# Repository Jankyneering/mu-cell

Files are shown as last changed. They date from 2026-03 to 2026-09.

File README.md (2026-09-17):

<h1 align="center">µCell</h1>

<p align="center">
	µCell logo
</p>

<p align="center">An open-source SDR base station platform for digital and analog voice modes.</p>

Got a board? Start with the [Quick Start Guide](docs/quickStartGuide.md).

---

## Contents

- [What is µCell?](#what-is-µcell)
- [Where to Buy](#where-to-buy)
- [Build Your Own](#build-your-own)
- [How the Software Fits Together](#how-the-software-fits-together)
- [Documentation](#documentation)
- [How to Contribute](#how-to-contribute)
- [Acknowledgements & License](#acknowledgements--license)

---

## What is µCell?

µCell is a software-defined radio base station/repeater/transceiver that runs on a Raspberry Pi.

The µCell BB board puts an SX1255 transceiver, its RF front-end, and a HAT identification EEPROM on a board that sits on a Pi 3, 4, 5, or Zero 2W. A single command installs the driver, and from there you pick the radio software you want to run.

The board presents itself as a standard SoapySDR device. The project started with TETRA, but DMR, D-Star, YSF, P25, and analog FM run on the same board through MMDVM-IQ, and general-purpose SDR software works with it directly. The goal is to support every voice mode we can reach.

Everything is open. Schematics, PCB layouts, production outputs, 3D printed case designs, drivers, and the EEPROM tooling are all in this repository, under licences that let you build, modify, and sell your own.

<p align="center">
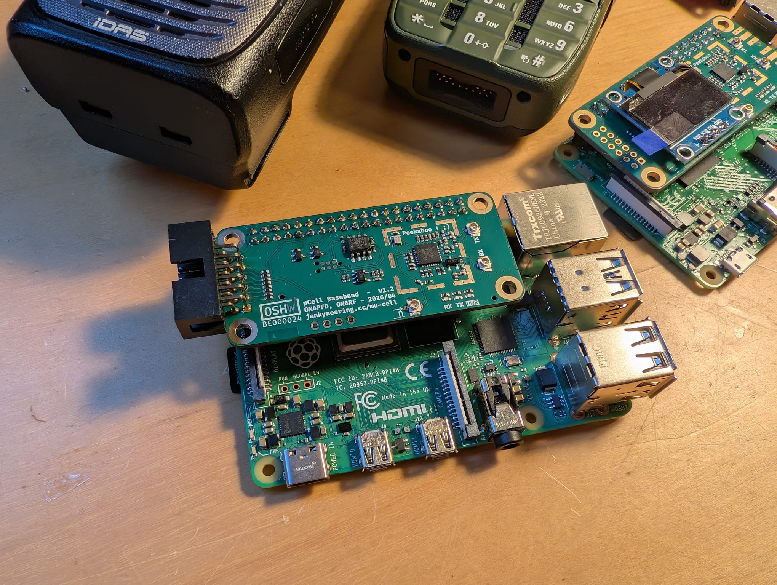
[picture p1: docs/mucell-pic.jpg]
µCell BB board
  
</p>

---

## Where to Buy

Assembled and tested µCell BB boards are sold by Fred Corp., one half of the Jankyneering team:

[store.fredcorp.cc](http://store.fredcorp.cc/)

Each board sold there is individually measured on an RF test set before shipping, and carries a signed EEPROM so the driver can confirm where it came from. See the [FAQ](docs/faq.md) for what signing does and does not mean.

---

## Build Your Own

The design is open and the production outputs are in this repository, ready to upload to a PCBA house. Component choice is critical: the RF path depends on inductor Q, capacitor dielectric, and a low drift referenceL. Foregoing proper part selection will affect sensitivity and output power.

See [docs/muCellBBManufacture.md](docs/muCellBBManufacture.md) for the production package contents, the stackup, the component selection notes, and the EEPROM writing procedure.

---

## Software structure

The stack has three layers.

### 1. µCell BB drivers

[mu-cell-bb-drivers](https://github.com/Jankyneering/mu-cell-bb-drivers) contains the device tree overlay that makes the Pi recognise the board, and `SoapyMuCell`, the hardware driver itself. The install script in this repository builds and installs both.

### 2. SoapySDR

`SoapyMuCell` registers with SoapySDR as the device `driver=mucell`. Any SoapySDR-aware application can open the board without knowing anything about the SX1255. This is the integration point: adding support for new software is usually a matter of pointing it at the right device string.

### 3. Applications

| Software | Modes | Status |
|---|---|---|
| [Flowstation](https://github.com/razvanzeces/flowstation) | TETRA, wider feature set, less stable | Supported |
| [Tetra-Bluestation](https://github.com/MidnightBlueLabs/tetra-bluestation) | TETRA, stable, fewer features | Supported on the testing branch, landing in main |
| [Nexus-BS](https://github.com/invictus737/nexus-bs/) | TETRA, different development direction than Flowstation | Untested, but claims support |
| [MMDVM-IQ](https://github.com/g4klx/MMDVM-IQ) | FM, DMR, D-Star, YSF, P25, POCSAG | Supported |

<!-- TODO: confirm the Bluestation branch wording, and whether MMDVM-IQ is "in progress" or already usable -->

Each of these is its own project with its own installation instructions. 
General-purpose SDR software reaches the board the same way, through the `driver=mucell` device string:

| Software | Status |
|---|---|
| [GQRX](https://www.gqrx.dk/) | Supported |
| [CubicSDR](https://cubicsdr.com/) | Supported |
| [GNU Radio](https://www.gnuradio.org/) | Should work through the Soapy blocks, more testing needed |
| [SDR++](https://www.sdrpp.org/) | Needs a dedicated source module, not yet written |

The [quick start guide](docs/quickStartGuide.md) covers how to point each one at the board.

---

## Documentation

| Document | Covers |
|---|---|
| [Quick Start Guide](docs/quickStartGuide.md) | Flash a Pi, install the driver, set up your radio software, get on air |
| [Building the Drivers](docs/buildDriver.md) | The driver and overlay built by hand, step by step, no scripts |
| [Hardware](docs/hardware.md) | Board specifications, connectors, measured performance, cases, roadmap |
| [Manufacturing](docs/muCellBBManufacture.md) | Production outputs, component selection, EEPROM writing and signing |
| [FAQ](docs/faq.md) | Common questions, support routes, the "not genuine" warning |

---

## How to Contribute

Contributions are welcome. For small fixes or documentation updates, feel free to open a pull request directly. For larger changes, open an issue first so the approach can be discussed. Keep pull requests focused and include a clear description of what changed and why.

Hardware contributions follow the same route. If you are proposing a layout or component change, include the reasoning and, where relevant, the measurements that back it up.

Support for a new mode or a new piece of SDR software is always of interest. If you get something working against `driver=mucell`, a short section for the quick start guide is a welcome contribution on its own.

---

## Acknowledgements & License

µCell builds on the work of several open-source projects:

- Tatu Peltola ([tejeez](https://github.com/tejeez/)), designer of the [SXCeiver](https://github.com/tejeez/sxxcvr), which provided early inspiration for compact SX1255-based SDR hardware.
- Wouter Bokslag ([Midnight Blue](https://github.com/MidnightBlueLabs/)) and contributors, authors of [TETRA-bluestation](https://github.com/MidnightBlueLabs/tetra-bluestation), which implements an open TETRA base station stack.

We also acknowledge the broader SDR and SoapySDR communities whose work enables hardware experimentation with modern radio systems.

Certified open source hardware by OSHWA under registration BE000024

OSHW BE000024 (https://certification.oshwa.org/be000024.html)

<!-- TODO: download the certification mark with the UID from the project page at certification.oshwa.org/be000024.html and commit it to docs/logos/. The link above assumes oshw-be000024.svg. -->

Hardware and documentation published under CreativeCommons BY-SA 4.0


[Creative Commons Attribution-ShareAlike 4.0 International License](http://creativecommons.org/licenses/by-sa/4.0/)

Software published under GNU GPLv3

License: GPL v3 (https://www.gnu.org/licenses/gpl-3.0.en.html)
[GNU GPLv3](https://www.gnu.org/licenses/gpl-3.0.en.html)

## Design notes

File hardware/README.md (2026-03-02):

# Hardware

Folder containing hardware design files, schematics, and documentation for the hardware side of the project.

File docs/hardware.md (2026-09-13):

# Hardware

The `hardware` directory contains the open hardware designs for the µCell ecosystem. Each board is a modular building block, so a system can be anything from a minimal hotspot to a more complete base station.

The platform is SDR-based and built around the SX1255 transceiver. The µCell driver exposes the board through SoapySDR, which is what lets it serve TETRA, DMR, D-Star, YSF, P25, analog FM, and whatever else gets added later without hardware changes.

Design files include schematics, PCB layouts, production outputs, case models, and the documentation needed for assembly and integration.

## Contents

- [Design goals](#design-goals)
- [µCell BB (Baseband)](#µcell-bb-baseband)
  - [Connectors and headers](#connectors-and-headers)
- [µCell Display](#µcell-display)
- [µCell PA Mini](#µcell-pa-mini)
- [Adding an amplifier](#adding-an-amplifier)
- [Cases](#cases)

---

## Design goals

- Modular architecture that scales from small hotspot deployments to higher power base stations
- SDR-based design that is not tied to any single radio mode
- Compatibility with Bluestation, Flowstation, MMDVM-IQ, and general SoapySDR software
- Readily available components wherever the RF performance allows it
- Reproducible designs suitable for small-scale manufacturing

---

## µCell BB (Baseband)

This is the board the project is built around, and the only one currently in production. It works on its own as a compact hotspot, and acts as the baseband and RF front-end when a PA board is added later.

<p align="center">
  µCell BB board
</p>

Features:

- SX1255 transceiver with RF filtering and matching network
- 38.4 MHz TCXO reference, 0.5 ppm, with an external clock option
- EEPROM for HAT identification, optionally signed
- U.FL connectors for TX, RX, and external clock
- Header for a standard SSD1306 OLED
- 12-pin IDC expansion connector
- Raspberry Pi HAT form factor, compatible with the Pi 3, 4, 5, and Zero 2W

Measured specifications (v1.0):

| Parameter | Value |
|---|---|
| Frequency coverage | 400 to 510 MHz |
| Rated output guaranteed | 430 to 440 MHz |
| Sample rates | 25, 50, 75, 150, 300, 600 kHz |
| Maximum signal bandwidth | 500 kHz |
| Tx power (Pi/4 DQPSK) | 0 to 3 dBm |
| Rx sensitivity (TETRA T1) | -117 dBm |

Coverage is set by the SX1255, which is specified for 400 to 510 MHz. The matching network is tuned for the 70 cm band, rated transmit power is guaranteed over 430 to 440 MHz. The board will tune and receive across the wider range, with output falling off towards the edges.

Sample rates are the reference clock divided down, following from the 38.4 MHz TCXO. The SX1255 digitises I and Q with 1-bit delta-sigma converters and decimates to the requested rate.

The SX1255 is designed for mobile devices, and its selectivity reflects that. On the bench, an interfering signal at -40 dBm and 10 MHz offset from the receive frequency is enough to start degrading the rated sensitivity. That is fine for a board transmitting a few dBm into its own antenna. It stops being fine as soon as you put an amplifier behind it. See [adding an amplifier](#adding-an-amplifier).

<!-- TODO: add supply current, and a measured figure for a non-TETRA mode, given the project is not TETRA-only. -->

Identification values written to the EEPROM:

| Field | Value |
|---|---|
| Vendor | Jankyneering |
| Product | µCell-BB |
| Product ID | `0x1255` |
| Current supply | 5000 mA |
| Device tree blob | `mu-cell-bb_raspberrypi` |

Boards sold by Jankyneering are individually tested on a radio test set to validate RF performance before shipping. See [muCellBBManufacture.md](muCellBBManufacture.md) if you want to build your own.

### Connectors and headers

#### External clock

A third U.FL connector accepts an external reference in place of the onboard TCXO. Useful if you have a GPSDO or a house standard, or if your application needs better than 0.5 ppm.

Boards ship using the onboard TCXO. To switch to the external input, cut JP1 on the back of the board and bridge the jumper to the external clock side.

Match the part you are replacing. The onboard reference is a Seiko Epson TG2016SMN 38.4000M-MCGNNM3: 38.4 MHz, sine output, ±0.5 ppm, running from the board's 3.3 V rail. An external source should be at 38.4 MHz with a comparable output level, and there is little point switching unless it is better than 0.5 ppm. The TCXO datasheet gives the exact output amplitude to aim for.

> Make sure your external source is present and at the right level before you cut, or the board will have no reference at all.

<!-- TODO: add a photo of JP1 on the back of the board -->

#### OLED display header

A 4-pin header for a standard 0.96 inch SSD1306 OLED, wired to the Pi's I2C bus.

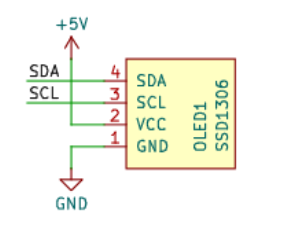
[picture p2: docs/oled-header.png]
SSD1306 OLED header schematic


| Pin | Signal |
|---|---|
| 1 | GND |
| 2 | VCC (+5V) |
| 3 | SCL |
| 4 | SDA |

There is no µCell software support for the display yet. It sits on the standard Pi I2C bus, so any existing SSD1306 library works in the meantime.

#### Expansion connector (J5)

A 2x6 12-position IDC connector on 2.54 mm pitch, for accessories and future modules, including the µCell Display. It breaks out power, the TX and RX lines, I2C, and two spare GPIOs. Every signal line goes through a 100R series resistor.

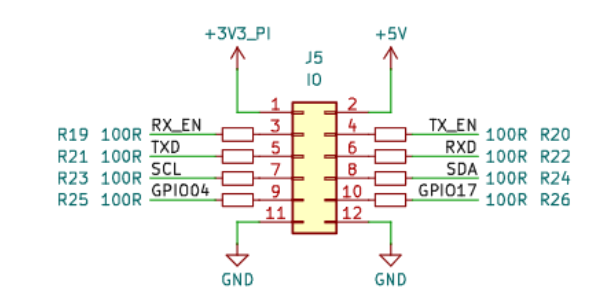
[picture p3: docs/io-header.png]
J5 expansion connector schematic


| Pin | Signal |
|---|---|
| 1 | +3V3 (from Pi) |
| 2 | +5V |
| 3 | RX_EN |
| 4 | TX_EN |
| 5 | TXD |
| 6 | RXD |
| 7 | SCL |
| 8 | SDA |
| 9 | GPIO04 |
| 10 | GPIO17 |
| 11 | GND |
| 12 | GND |

---

## µCell Display

A front panel module for builds that go into an enclosure, connecting through J5. The design is nearing completion.

Features:

- 0.96 inch SSD1306 OLED for status
- Rotary encoder for local control
- Status LEDs

<!-- TODO: add panel dimensions and a photo once the design is finalised -->

---

## µCell PA Mini

A low power RF front-end that extends the µCell BB. The design exists but there is still a fair amount of work left before it is ready to manufacture.

Planned features:

- Roughly 1 W RF power amplifier
- Receive path conditioning with an LNA
- Preselector filtering
- RF measurement and monitoring points

---

## Adding an amplifier

The µCell BB is a bare transceiver board. The matching network and filtering on it were designed to get the most output power and sensitivity out of the SX1255, and a board on its own has harmonics well within spec. Anything you put after it is your responsibility, and the SX1255 was designed for handheld and mobile equipment rather than for driving a power amplifier.

Two things matter once you amplify: linearity and filtering.

### Linearity

Modes with a non-constant envelope, TETRA among them, need a linear amplification chain. Constant-envelope modes such as FM and 4FSK are far more forgiving, so how much of this applies depends on what you are running.

The problem is rarely harmonic distortion. It is inter-channel interference, seen as increased adjacent channel power. As an amplifier is driven towards its P1dB point, the output level at which gain compression sets in, non-linear effects grow quickly. The carrier can still look clean while energy spreads into the channels either side of it.

A TETRA amplification stages usually follow these guidelines:

- Running far below P1dB, by oversizing the amplifier deliberately. A 10 W rated device producing 1 W of RF is a normal ratio.
- Using Class A or Class AB operation, which is one reason TETRA transmitter efficiency rarely exceeds about 20%.
- Adding a linearisation loop, often a Cartesian loop, which measures the distortion and pre-corrects the signal so the non-linear effects cancel out.

Those measures go together with tight filtering and closed loop power control. For lab, experimental, and amateur work, staying well below P1dB already gives acceptable results on its own.

The Bluestation documentation covers this in more depth and has worked examples: [Miscellaneous](https://github.com/MidnightBlueLabs/tetra-bluestation-docs/wiki/20-Miscellaneous).

### Filtering

Transmit filtering is the amplifier chain's job. 

Receive rejection matters just as much. The measured figure gives a sense of the margin available: a -40 dBm interferer 10 MHz away from the receive frequency already starts degrading rated sensitivity. Your own transmitter, amplified, is far stronger than that and far closer in frequency. Without proper rejection between the two paths, a duplexer or cavity filtering depending on what you are building, the receiver will be deaf whenever the transmitter is keyed.

None of this is exotic for anyone who has built a repeater before. It is worth saying plainly because the board is small and cheap enough to make a 100 W base station look like a matter of bolting on an amplifier, and it is not.

---

## Cases

3D printable case designs are in the `hardware` directory alongside the board files, under the same CC BY-SA 4.0 licence. They are designed to print without supports on a standard FDM machine.

<!-- TODO: give the exact path to the case models, the file formats provided (STL, STEP, source), and which Pi models each case fits -->

If you print one and find something that needs adjusting, a pull request with the change and a note on your print settings is welcome.

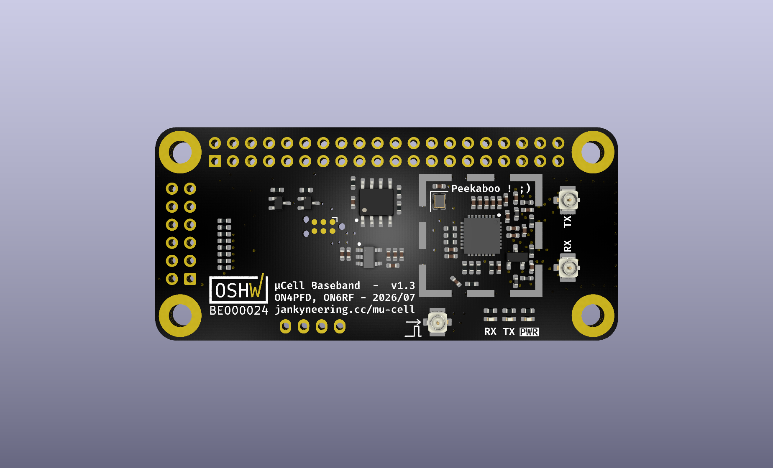
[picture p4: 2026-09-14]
hardware/mu-cell-bb/images/mu-cell-bb-top.png

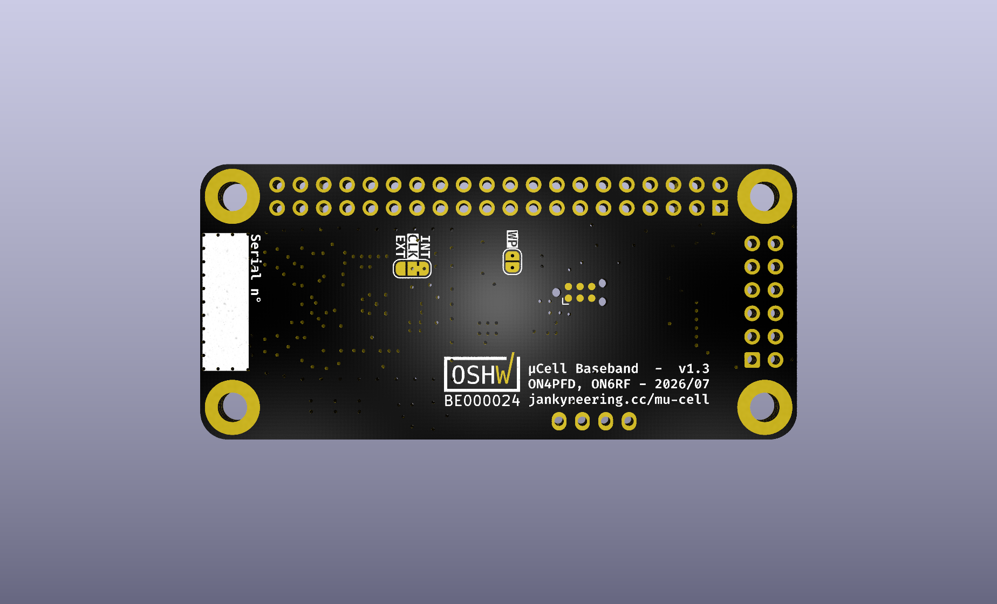
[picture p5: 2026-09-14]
hardware/mu-cell-bb/images/mu-cell-bb-bottom.png

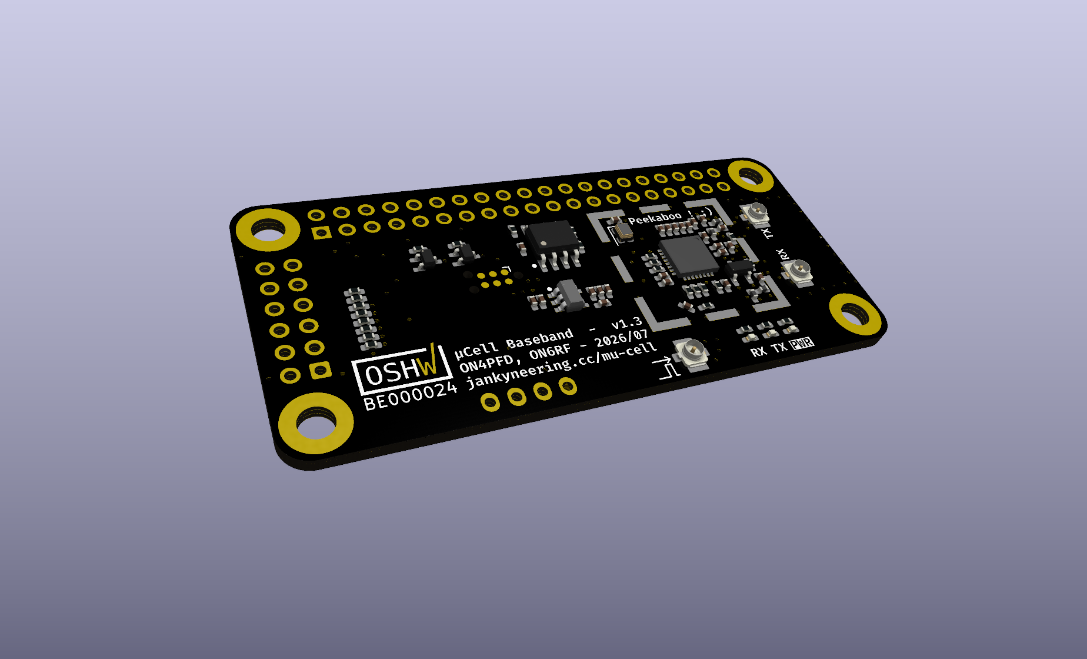
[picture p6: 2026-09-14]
hardware/mu-cell-bb/images/mu-cell-bb-3-4.png

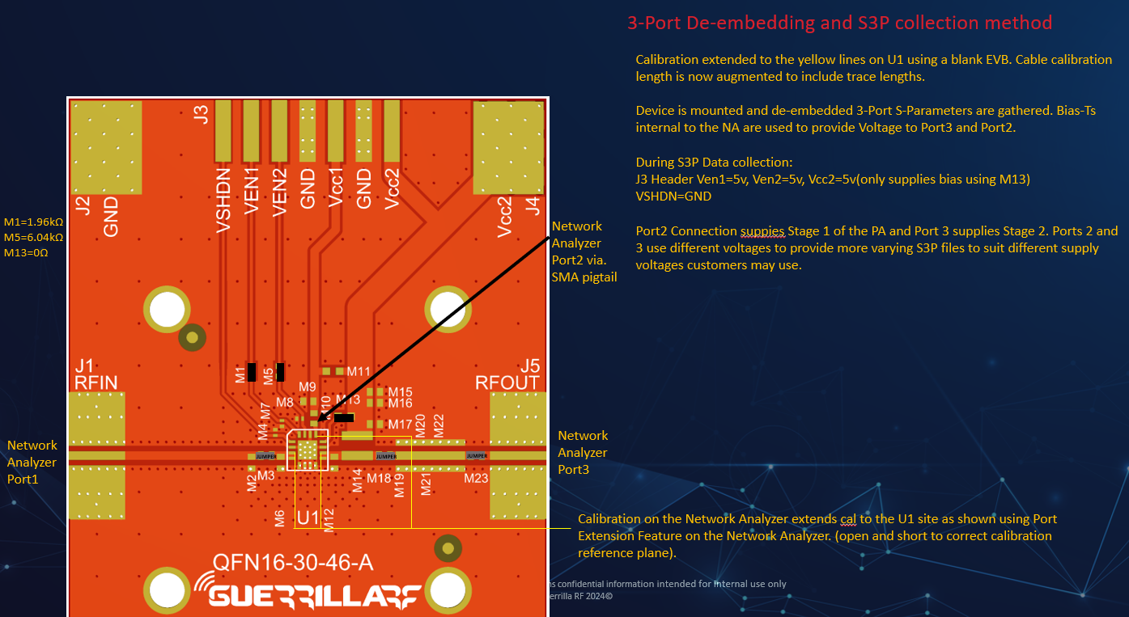
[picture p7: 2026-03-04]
sim/qucs/GRF5604_S3P/GRF5604_3Port_Deembed_Process.png

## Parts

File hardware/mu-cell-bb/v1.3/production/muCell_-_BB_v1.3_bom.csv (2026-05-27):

Designator | Footprint | Quantity | Value | LCSC Part #
_2, | e7774905-3e1b-474f-b2b7-99bac235eba3 | 2
C1, C2, C6, C8 | 0402 | 4 | 100p | C2941926
C10, C11, C12, C14, C16, C21, C24, C7, C9 | 0402 | 9 | 100n | C60474
C13, C15, C17, C18, C19, C22 | 0402 | 6 | 10n | C60133
C20, C23 | 0402 | 2 | 1u | C29266
C25 | 0402 | 1 | 4.7u | C23733
C3 | 0402 | 1 | 3.3p | C2941931
C4 | 0402 | 1 | 8.2p | C2857971
C5 | 0402 | 1 | 6.8p | C1864373
D1 | SOT-23-3 | 1 | BAV99,215 | C2500
IC1 | QFN50P500X500X80-33N-D | 1 | SX1255IWLTRT | C89372
J1 | U.FL_Vertical_Passthrough | 1 | TX | C5137195
J2 | U.FL_Vertical_Passthrough | 1 | RX | C5137195
J3 | U.FL_Vertical_GND | 1 | EXT_CLK | C5137195
L1, L3, L4 | 0402 | 3 | 39n | C40399699
L2 | 0402 | 1 | 22n | C22440906
LED1 | 0402 | 1 | Red | C7496803
LED2 | 0402 | 1 | Amber | C5123495
LED3 | 0402 | 1 | Green | C74338
Q1, Q2 | SOT-323_SC-70 | 2 | BC817-40W | C383187
R1, R19, R2, R20, R21, R22, R23, R24, R25, R26, R3, R4, R5, R6, R7 | 0402 | 15 | 100R | C106232
R10, R8, R9 | 0402 | 3 | 1M | C26083
R11, R12, R13 | 0402 | 3 | 3K9 | C2909346
R14, R15, R16, R17, R18 | 0402 | 5 | 1K | C106235
U1 | SOIC-8_3.9x4.9mm_P1.27mm | 1 | 24LC256 | C615210
U2 | SOT23-5L_1P75X3P05X0P95_STM | 1 | LDK130M33R | C2969807
Y1 | Crystal_SMD_2016-4Pin_2.0x1.6mm | 1 | 38.4MHz | C1987359

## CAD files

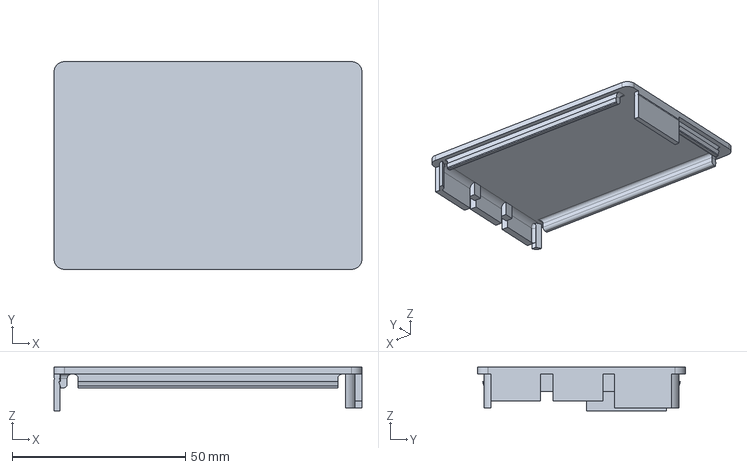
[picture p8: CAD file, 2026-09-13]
hardware/3d-print/Case.FCStd
89.0 x 60.0 x 12.6 mm

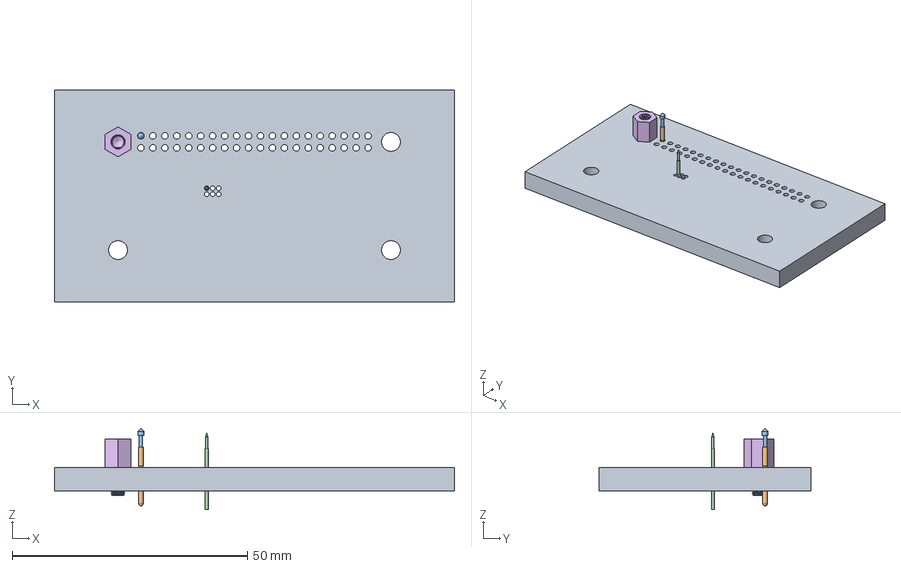
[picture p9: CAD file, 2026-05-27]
hardware/mu-cell-bb/CAD/mu-cell-bb_testbench-fixture.FCStd
85.0 x 45.0 x 17.3 mm
pin
P50-E1
root

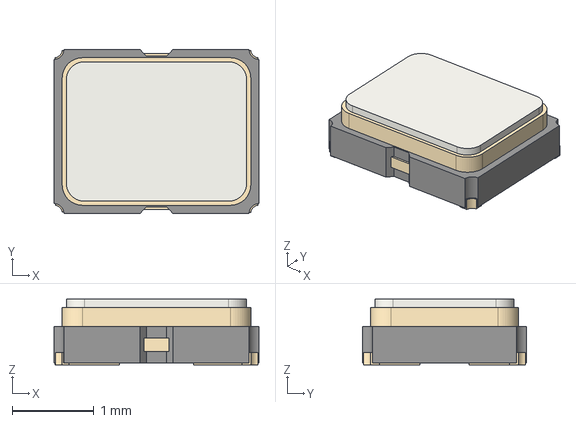
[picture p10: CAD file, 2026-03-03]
hardware/mu-cell-bb/parts/3D/Oscillator_SMD_SeikoEpson_SG210-4Pin_2.5x2.0mm.step
2.50 x 2.00 x 0.8 mm

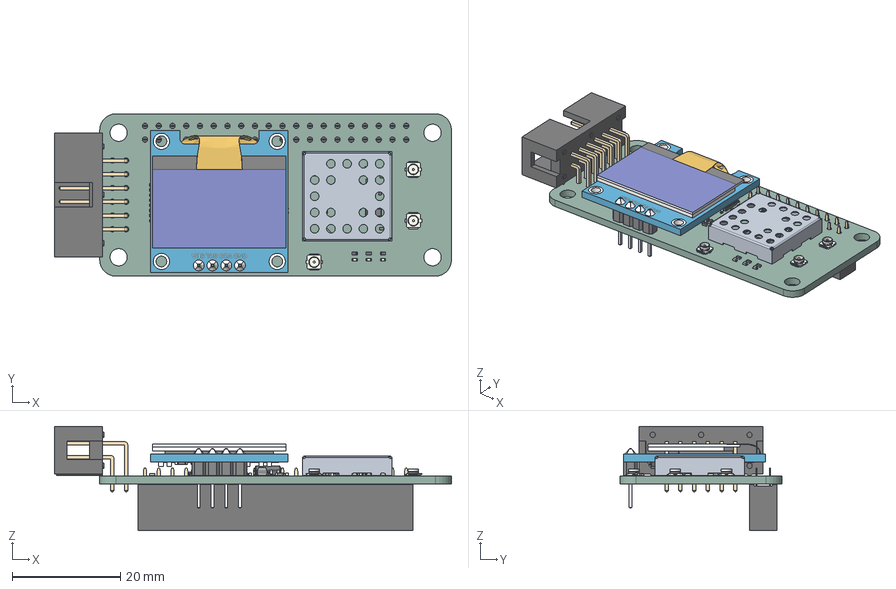
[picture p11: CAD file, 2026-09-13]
hardware/3d-print/muCell.step
73.3 x 30.0 x 19.3 mm
R_0402_1005Metric x 26
U.FL_Hirose_U.FL-R-SMT-1_Vertical x 2
SOT-323_SC-70 x 2
C_0402_1005Metric x 25
L_0402_1005Metric x 4
SOT23-5L_1P75X3P05X0P95_STM
2118707-4-CAN
Crystal_SMD_2016-4Pin_2.0x1.6mm
IDC-Header_2x06_P2.54mm_Horizontal
SOIC-8_3.9x4.9mm_P1.27mm
SOT-23-3
board
screen
pin_header
soldering
smd_capacitor
smd_capacitor (1)
914_smd_resistor
472_smd_resistor x 3
t4_smd_diode
smd_capacitor (2)
smd_capacitor (3)
smd_capacitor (4)
smd_capacitor (5)
smd_capacitor (6)
472_smd_resistor (1)
SOT-23_XC6206 v3
smd_capacitor (7)
flat_cable
LED_0402_1005Metric x 3
U.FL_Vertical
ThermalPin
PinsArrayLR
PinsArrayTB
PinSocket_2x20_P2.54mm_Vertical
mu-cell-bb_PCB

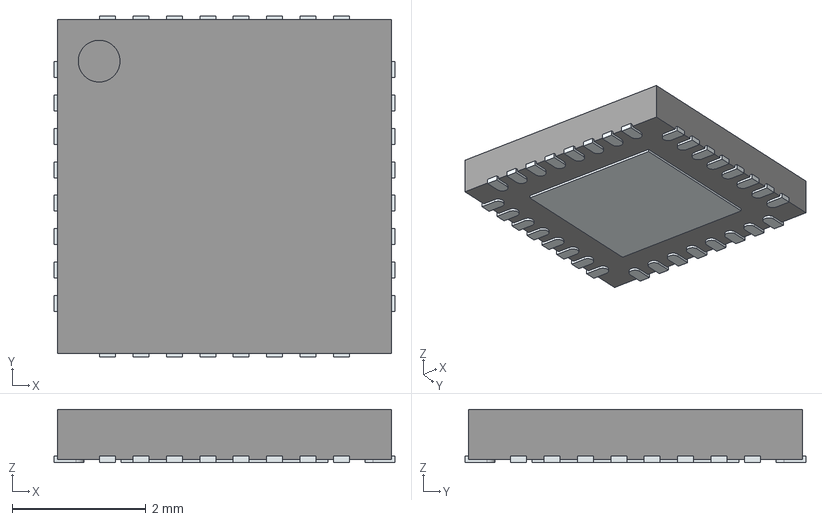
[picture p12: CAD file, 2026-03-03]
hardware/mu-cell-bb/parts/3D/SX1255IWLTRT.stp
5.10 x 5.10 x 0.8 mm
ThermalPin
PinsArrayLR
PinsArrayTB

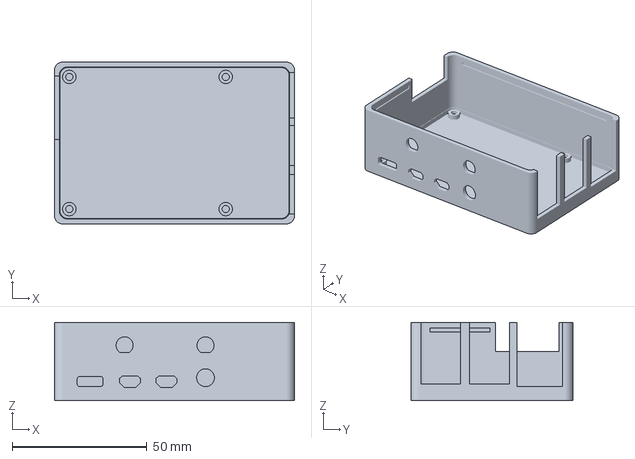
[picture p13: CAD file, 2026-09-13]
hardware/3d-print/Case_Bottom_Pi4.3mf
89.0 x 60.0 x 29.0 mm

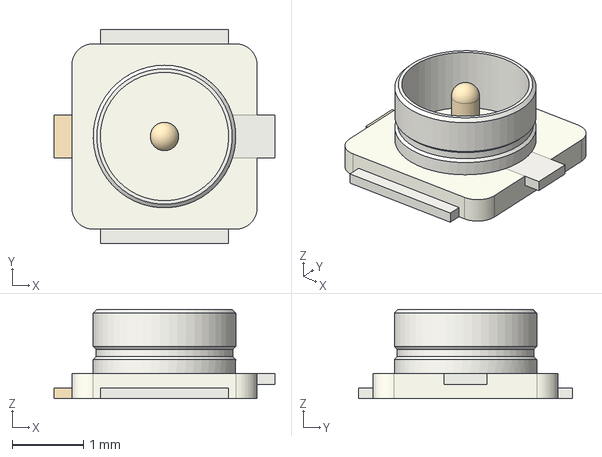
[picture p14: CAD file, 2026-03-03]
hardware/mu-cell-bb/parts/3D/U.FL_Vertical.step
3.10 x 3.00 x 1.25 mm

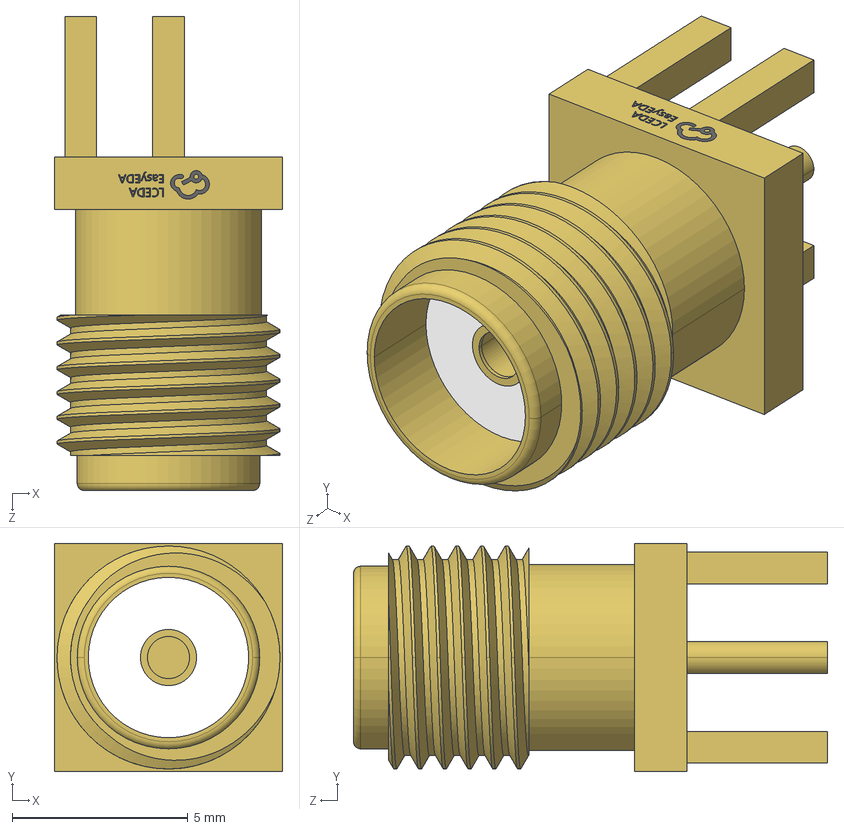
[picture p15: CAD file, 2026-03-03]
hardware/mu-cell-bb/parts/3D/SMA_Side.step
6.50 x 6.50 x 13.5 mm

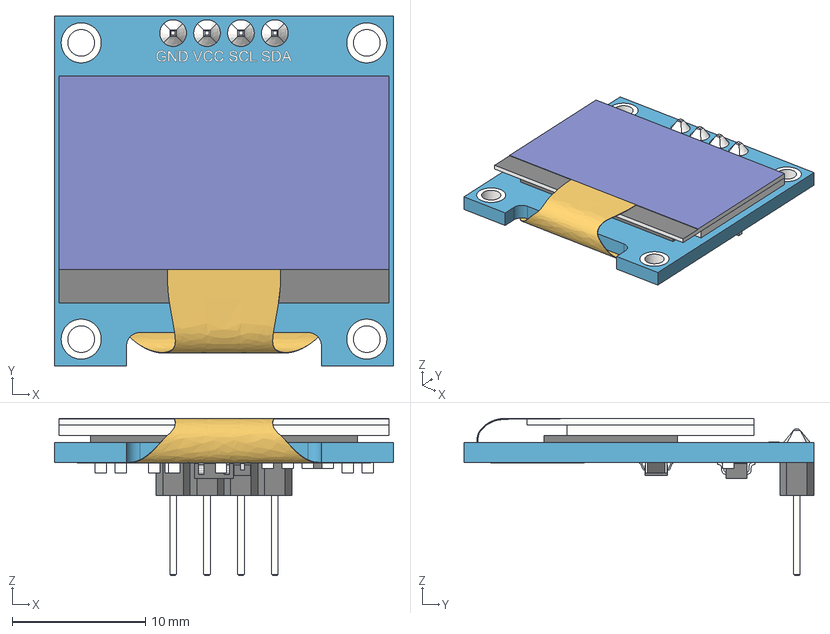
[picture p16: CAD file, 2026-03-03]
hardware/mu-cell-bb/parts/3D/OLED_128x64_I2C.step
25.4 x 26.2 x 11.8 mm
board
screen
pin_header
soldering
smd_capacitor
smd_capacitor (1)
914_smd_resistor
472_smd_resistor x 3
t4_smd_diode
smd_capacitor (2)
smd_capacitor (3)
smd_capacitor (4)
smd_capacitor (5)
smd_capacitor (6)
472_smd_resistor (1)
SOT-23_XC6206 v3
smd_capacitor (7)
flat_cable

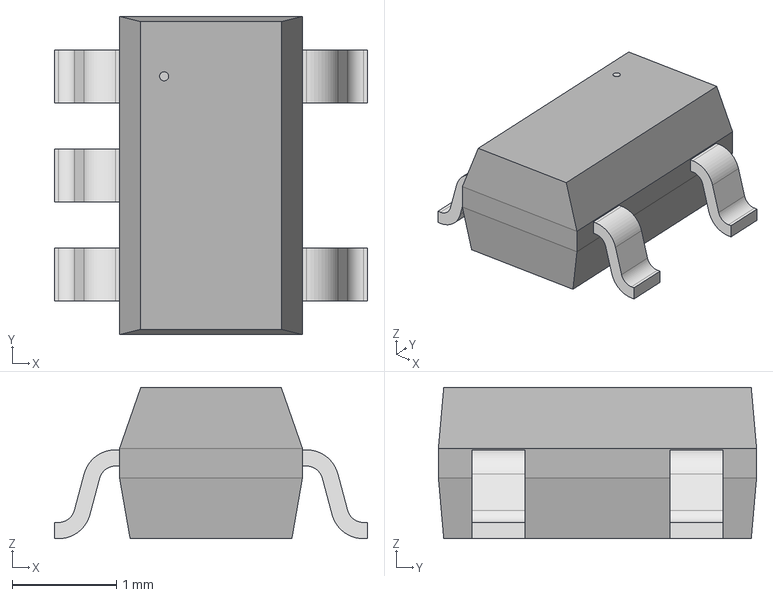
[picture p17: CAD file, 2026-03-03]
hardware/mu-cell-bb/parts/3D/SOT23-5L_1P75X3P05X0P95_STM.step
3.00 x 3.05 x 1.45 mm

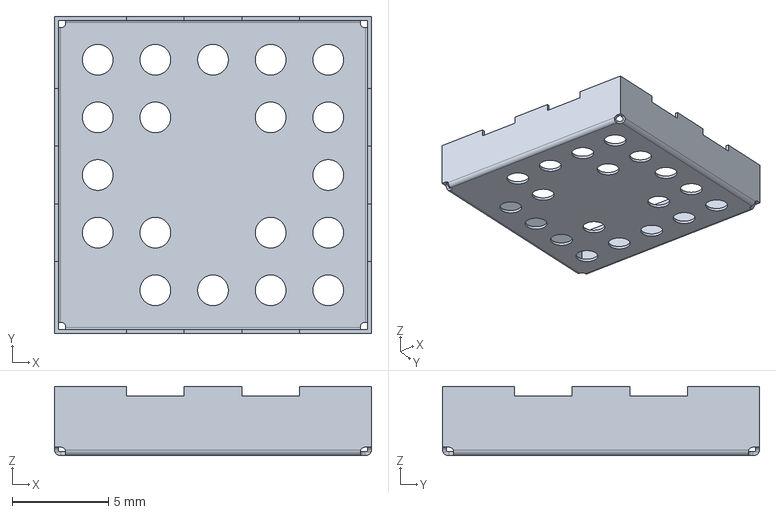
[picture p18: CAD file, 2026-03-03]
hardware/mu-cell-bb/parts/3D/2118707-4-CAN.STEP
16.5 x 16.5 x 3.60 mm

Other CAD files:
hardware/3d-print/Case-Case_Top_Pi4.3mf

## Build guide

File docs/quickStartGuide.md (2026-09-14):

# Quick Start Guide

This gets a µCell board running on a Raspberry Pi, from a blank SD card to working radio software.

If you would rather build the driver by hand instead of running an install script, see [buildDriver.md](buildDriver.md).

## Contents

- [What you need](#what-you-need)
- [Part 1: Install the board and driver](#part-1-install-the-board-and-driver)
  - [1. Flash and boot](#1-flash-and-boot)
  - [2. Run the install script](#2-run-the-install-script)
  - [3. Verify the driver](#3-verify-the-driver)
- [Part 2: Install and configure your radio software](#part-2-install-and-configure-your-radio-software)
  - [Flowstation](#flowstation)
  - [Tetra-Bluestation](#tetra-bluestation)
  - [MMDVM-IQ](#mmdvm-iq)
  - [Other SoapySDR software](#other-soapysdr-software)
- [Updating](#updating)
- [Troubleshooting](#troubleshooting)

---

## Equiment needed

- A Raspberry Pi 3, 4, 5, or Zero 2W
- A µCell BB board connected to the Pi
- A microSD card with Raspberry Pi OS Lite (64-bit)

Fit the board before you start. The device tree overlay only loads when the Pi detects the µCell on the GPIO header, so a Pi booted without the board will behave as though nothing is installed.

---

## Part 1: Install the board and driver

This part is the same regardless of which radio software you plan to run.

### 1. Flash and boot

Flash Raspberry Pi OS Lite (64-bit) to your microSD card using the [Raspberry Pi Imager](https://www.raspberrypi.com/software/). Enable SSH in the imager settings before writing, then boot the Pi and connect over SSH.

### 2. Run the install script

```bash
bash -c "$(curl -fsSL https://raw.githubusercontent.com/Jankyneering/mu-cell/main/install-mu-cell-sw.sh)"
```

The script will:

- Install the required system dependencies
- Clone the µCell baseband driver repository
- Build and install the device tree overlay
- Build and install the SoapyMuCell driver

> A reboot is required after the first install so the device tree overlay loads. The script will prompt you. Run it again after rebooting to verify the driver.

### 3. Verify the driver

After the reboot, the script probes the driver for you. To check it yourself at any point:

```bash
SoapySDRUtil --probe=driver=mucell
```

The driver reports the EEPROM contents during initialisation, including vendor, product, serial, and whether the signature matched a known key. A warning about an unsigned or unrecognised board does not stop it from working. See the [FAQ](faq.md) for what that means.

Once the probe succeeds, the board is ready and any SoapySDR application can use it.

---

## Part 2: Install and configure your radio software

Each of these is a separate project with its own releases and its own documentation. Pick the one you want, install it from upstream, then use the notes here for the µCell-specific parts.

### Flowstation

TETRA base station software with a wide feature set, at the cost of some stability. It publishes pre-built binaries that already work with µCell, which makes it the fastest route to a running cell.

On the Pi, fetch the binary and make it executable:

```bash
wget https://github.com/razvanzeces/flowstation/releases/download/v0.4.0/bluestation-bs
chmod +x bluestation-bs
```

Check the [releases page](https://github.com/razvanzeces/flowstation/releases) for a newer version than the one above.

Generate a `config.toml` for your cell with the configuration tool:

https://bluestation.russel053.com/

Either copy/paste the contents of the generated file via SSH (while editing config.toml for instance), or transfer the file via scp:

```bash
scp config.toml <user>@<pi-address>:~/
```

Then start the base station:

```bash
./bluestation-bs ./config.toml
```

### Tetra-Bluestation

Stable TETRA base station software with a smaller feature set.

µCell support currently lives on the testing branch and is expected to land in main. Get it from the [project repository](https://github.com/MidnightBlueLabs/tetra-bluestation), and build from source. Pi 5 and earlier Pi models use different builds, so pick the matching asset.

It uses the same binary name and the same configuration format as Flowstation, so the configuration tool above works for it too and the command to start it is identical:

```bash
./bluestation-bs ./config.toml
```

Keep them in separate directories if you want both on the same Pi.

### MMDVM-IQ

Multi-mode digital voice: FM, DMR, D-Star, YSF, P25, and others. Support is in progress.

Follow the build and configuration instructions in the [upstream repository](https://github.com/g4klx/MMDVM-IQ), and point it at the SoapySDR device `driver=mucell`.

### Other SoapySDR software

The µCell BB registers as a standard SoapySDR device, so anything that speaks SoapySDR can use it. With the board fitted and the driver from Part 1 installed, most sofware will list it in the available devices. 

| Software | Status |
|---|---|
| GQRX | Supported. The board appears in the device dropdown, select it and go. |
| CubicSDR | Tested working. Picked up at startup. |
| GNU Radio | Should work through the Soapy Source and Sink blocks. Lightly tested so far. |
| SDR++ | Needs a dedicated source module, which has not been written yet. |

If you ever do need to name the device by hand, for a GNU Radio block or a command line tool, the string is:

```
driver=mucell
```

<!-- TODO: this section is the extension point. When a new mode or stack is brought up, add a sibling heading here with a link upstream. -->
---

## Updating

Re-run the install script to update the driver and overlay:

```bash
bash -c "$(curl -fsSL https://raw.githubusercontent.com/Jankyneering/mu-cell/main/install-mu-cell-sw.sh)"
```

It checks the driver repository for new commits and rebuilds only if there are any. If nothing has changed, it says so and exits.

This is also how you pick up new EEPROM signing keys. If a board bought from the store started warning that it is not genuine, a driver update is usually the fix.

Radio software is updated through its own project, following whatever process that project uses.

---

## Troubleshooting

The driver probe fails right after install
: Reboot. The overlay is only read at boot. Re-run the install script afterwards.

The probe fails after a reboot
: Check that the board is seated properly on the GPIO header. The overlay will not load without it. Look for the HAT in the device tree with `ls /proc/device-tree/hat/`. If that directory is missing, the Pi is not seeing the EEPROM.

The driver warns that no public keys are compiled in
: The driver was built without any `.pem` files in `public_keys/`. It still works. Rebuild with the keys present if you want signature checking.

The radio starts but the frequency is off
: If you cut JP1 to use an external reference, check that the external source is present and at the right level. See [hardware.md](hardware.md#external-clock). If you want to use the internal source and need better accuary, compensate it in software (most implement a ppm correction line in the configuration files).

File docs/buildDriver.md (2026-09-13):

# Building the Drivers Manually

The [install script](quickStartGuide.md) does everything on this page for you. This is the same procedure done by hand, for anyone who would rather not pipe a script into bash, or who is porting the driver somewhere the script does not cover.

This page covers the device tree overlay and the SoapySDR driver, which is all µCell maintains. The radio software that sits on top is maintained by other projects, and their own documentation is the right place for build instructions. Once the driver is installed, any of them can reach the board through `driver=mucell`.

Every step below corresponds to a function in `install-mu-cell-sw.sh`, so you can read the script alongside this page.

## Contents

- [1. System dependencies](#1-system-dependencies)
- [2. Clone the driver repository](#2-clone-the-driver-repository)
- [3. Build and install the device tree overlay](#3-build-and-install-the-device-tree-overlay)
- [4. Build and install SoapyMuCell](#4-build-and-install-soapymucell)
- [5. Verify](#5-verify)
- [Next steps](#next-steps)

---

## 1. System dependencies

```bash
sudo apt update
sudo apt install -y --no-install-recommends \
  git make g++ cmake \
  libsoapysdr-dev soapysdr-tools libasound2-dev python3-soapysdr \
  libssl-dev clang llvm-dev libclang-dev
```

What these are for:

| Package group | Why |
|---|---|
| `git make g++ cmake` | Build toolchain |
| `libsoapysdr-dev soapysdr-tools python3-soapysdr` | SoapySDR headers, the `SoapySDRUtil` probe tool, and Python bindings |
| `libasound2-dev` | ALSA, used for the sample interface |
| `libssl-dev` | OpenSSL, required for EEPROM signature verification |
| `clang llvm-dev libclang-dev` | Needed by the build |

---

## 2. Clone the driver repository

```bash
git clone https://github.com/Jankyneering/mu-cell-bb-drivers ~/mu-cell-bb-drivers
```

The install script clones into `$HOME/mu-cell-bb-drivers`. The paths below assume the same.

To update an existing clone instead:

```bash
cd ~/mu-cell-bb-drivers
git fetch origin
git pull --ff-only
```

If the pull brings in changes, rebuild both the overlay and the driver before using the board again.

---

## 3. Build and install the device tree overlay

The overlay tells the Pi how to talk to the board. Without it, the driver has nothing to attach to.

Fit the µCell to the GPIO header before you go any further. The overlay is loaded from the HAT EEPROM at boot, so it will not load at all on a Pi with no board attached.

```bash
cd ~/mu-cell-bb-drivers/raspberry-pi-drivers/mu-cell-bb-dts
make overlay
sudo make install
```

`make overlay` compiles `mu-cell-bb_raspberrypi.dts` into a `.dtbo` in `build/`. `make install` copies it to the overlays directory, which is `/boot/firmware/overlays` on current Raspberry Pi OS and `/boot/overlays` on older releases. The Makefile detects which one you have.

Reboot now:

```bash
sudo reboot
```

The overlay is only read at boot, so nothing below will work until you have done this.

---

## 4. Build and install SoapyMuCell

```bash
cd ~/mu-cell-bb-drivers/SoapyMuCell
mkdir -p build
cd build
cmake ..
make
sudo make install
sudo ldconfig
```

During configuration, CMake scans `public_keys/` and embeds every `.pem` file it finds into `generated_keys.hpp`. Each key is named after its filename, so batch keys show up by name in the driver log. If the directory is empty, CMake prints a warning and the driver reports `NO_KEYS_COMPILED_IN` at runtime. That is not fatal, it just means signature checking is off.

---

## 5. Verify

```bash
SoapySDRUtil --probe=driver=mucell
```

On success the driver logs a line summarising the EEPROM, for example:

```
HAT EEPROM: Vendor="Jankyneering" Product="µCell-BB" UUID=... HW=1.0 Serial=... Auth=GENUINE (key: batch_001)
```

Possible `Auth` values and what they mean:

| Value | Meaning |
|---|---|
| `GENUINE` | Signature matched one of the compiled-in keys |
| `NO_SIGNATURE` | The EEPROM has no signature atom. Normal for boards you wrote yourself |
| `SIGNATURE_MISMATCH` | A signature is present but matches no known key. Often an out-of-date driver |
| `NO_KEYS_COMPILED_IN` | Built without any `.pem` files in `public_keys/` |
| `EEPROM_NOT_FOUND` | The Pi is not seeing the HAT EEPROM at all. Check the board is seated |

None of these block operation. The driver warns and carries on.

---

## Next steps

The driver is now installed and the board is a standard SoapySDR device. Install whichever radio software you want according to its own documentation, and point it at `driver=mucell`.

[quickStartGuide.md](quickStartGuide.md#part-2-configure-your-software) has a short configuration section for each stack we have tested, with links upstream.

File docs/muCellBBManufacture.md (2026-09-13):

# Manufacturing a µCell BB

Everything needed to have a µCell BB built is in this repository. This page covers ordering the boards, the component choices that actually matter, and writing the EEPROM afterwards.

Boards sold through [store.fredcorp.cc](http://store.fredcorp.cc/) are individually tested on a radio test set to validate RF performance before they ship. If you build your own, that verification step is on you, and the section on [testing](#testing-what-you-built) is worth reading before you order a large batch.

## Contents

- [The production package](#the-production-package)
- [Board settings](#board-settings)
- [Component selection](#component-selection)
- [Testing what you built](#testing-what-you-built)
- [Writing the EEPROM](#writing-the-eeprom)
- [Signing](#signing)
- [Support for boards you built yourself](#support-for-boards-you-built-yourself)

---

## The production package

Production outputs live under `/hardware/mu-cell-bb/<version>/production`. For the current revision that is:

```
/hardware/mu-cell-bb/v1.3/production
```

| File | Purpose |
|---|---|
| Gerber zip | Copper, mask, silkscreen, and drill data. Upload as-is |
| BOM CSV | Component list with LCSC part numbers |
| Designators CSV | Reference designator list for assembly |
| Positions CSV | Component positions and rotations |
| IPC netlist | Netlist for electrical test and for verifying the gerbers match the schematic |

Upload the gerber zip in the JLCPCB order form, then attach the BOM and positions files in the assembly step. The parts list uses LCSC numbers so the matching is automatic for most lines.

The IPC netlist is worth uploading too where the fab accepts it. It lets them catch a gerber that does not match the intended connectivity before anything is etched.

---

## Board settings

These are the settings used for the boards Jankyneering manufactures.

| Setting | Value |
|---|---|
| Layers | 4 |
| Thickness | 1.6 mm |
| Outer copper weight | 1 oz |
| Inner copper weight | 0.5 oz |
| Impedance control | None specified |
| Surface finish | ENIG recommended |

No controlled impedance was ordered. The RF traces were designed against the standard 4-layer 1.6 mm stackup, and the measured performance in [hardware.md](hardware.md) was achieved without it. Changing the layer count or the overall thickness changes the trace impedance, which shows up as lost output power and degraded sensitivity, so keep the stackup as listed rather than treating these numbers as defaults.

---

## Component selection

The BOM specifies parts rather than values for a reason. Assembly houses substitute freely when a line is out of stock, and for most of this board that is fine. For the RF path it is not.

The full list is in the BOM CSV in the production folder, with an LCSC number on every line. Look those numbers up rather than reading values off the schematic: the parts chosen carry tolerance, dielectric, and Q figures that a value alone does not capture. The categories below are the ones to check before approving any substitution.

### Reference clock

Y1 is a 38.4 MHz TCXO. Frequency accuracy and stability over temperature set the carrier accuracy of the whole radio, and several of the modes the board targets have demanding requirements there. The board is built with a 0.5 ppm part.

Any TCXO meeting the same specification works. What matters is the frequency, the stability figure, the output type and level the SX1255 expects, and the supply voltage. Do not substitute on frequency alone: a plain crystal, or a TCXO an order of magnitude looser, will pass a bench test and then drift out as the board warms up.

If you need better than the onboard part gives you, an external reference can be fed in through J3 instead. See [hardware.md](hardware.md#external-clock) for how to switch the board over.

### Inductors in the matching network and filters

Q factor is the parameter that matters, not just inductance. A part with the correct value but a lower Q will widen the filter response and eat transmit power.

L2 gives the standard to work to. It is a Coilcraft 0402CS-22NXGRW, 22 nH, with Q of 53 at 900 MHz and 53 at 1.7 GHz. That is a wirewound ceramic part, and a general-purpose multilayer 22 nH inductor is not a substitute for it even though a BOM matcher will treat them as the same line.

Check Q at your operating frequency rather than the datasheet headline figure, which is usually quoted much lower down, and make sure the self-resonant frequency sits well above the band of operation.

### Capacitors in the RF path

C3, C4, and C5 set the matching network, and C1, C2, C6, and C8 sit in the RF path. Use the parts the BOM lists.

C5 shows the level of part these lines need: a Murata GCM1555C1H6R8FA16D, 6.8 pF, C0G dielectric, 50 V, in 0402. C0G is the requirement, not a preference. X7R and X5R have voltage and temperature coefficients large enough to detune a matching network, and they are microphonic. A 6.8 pF X7R part is not a substitute even though a BOM line matcher will treat them as the same value.

Tolerance matters too, since loosening it spreads your performance across a batch.

### Everything else

Decoupling capacitors, pull-up resistors, LEDs, and the transistors tolerate substitution without much consequence. The EEPROM should be a 24LC256 or compatible part, since that is what the write tooling assumes.

---

## Testing what you built

At minimum, before calling a board good:

1. Check the supply rails.
2. Write the EEPROM, then confirm the Pi sees the HAT: `ls /proc/device-tree/hat/`
3. Probe the driver: `SoapySDRUtil --probe=driver=mucell`
4. Measure transmit power and receive sensitivity against the figures in [hardware.md](hardware.md).

Step 4 is the one that needs equipment. A board can pass every digital check and still be 6 dB down because of one wrong inductor. If you do not have access to a radio test set, or a spectrum analyser with a signal generator, consider building a small first batch and having it measured before committing to a larger run.

---

## Writing the EEPROM

The EEPROM identifies the board to the Raspberry Pi as a HAT. Without it the Pi will not load the device tree overlay and the driver will not find the board.

### Prerequisites

You need `eepmake` and `eepflash` from the Raspberry Pi utilities, plus `dtc`:

```bash
git clone https://github.com/raspberrypi/utils
cd utils/eeptools
cmake .
make
sudo make install
```

Full documentation for those tools is in the [eeptools repository](https://github.com/raspberrypi/utils/tree/master/eeptools).

### Writing

With the board connected to a Pi:

```bash
cd raspberry-pi-drivers/mu-cell-bb-dts
make all
make write_eeprom
```

`make all` generates `build/eeprom_settings.txt`, turns it into `build/eeprom.bin` with `eepmake`, and compiles the device tree overlay. `make write_eeprom` writes the image over I2C and then verifies the readback.

The Makefile prints the settings it is about to use before writing. Check them:

```
=== EEPROM settings ===
HAT UUID    : ...
HAT version : 0x...
TX pin      : 22
RX pin      : 23
```

The UUID and version are read from an already-connected HAT if one is present, and fall back to zeros otherwise. For a fresh board you will want to set a real UUID rather than writing all zeros.

<!-- TODO: document how you generate and assign UUIDs and serial numbers for a production batch. The Makefile reads them from a connected HAT, which does not help on a blank board. -->

Fixed values written for every µCell BB:

| Field | Value |
|---|---|
| `product_id` | `0x1255` |
| `vendor` | `Jankyneering` |
| `product` | `µCell-BB` |
| `current_supply` | `5000` |
| `dt_blob` | `mu-cell-bb_raspberrypi` |

---

## Signing

Signing is optional. Read that sentence again before continuing, because the rest of this section is easy to misread.

### What signing does

The [eeprom-sign](https://github.com/fred-corp/eeprom-sign) tool adds an RSA-2048 / SHA-256 / PSS signature over the EEPROM contents, stored in an `RSIG` custom atom. The driver has public keys compiled in from `SoapyMuCell/public_keys/`, and checks the signature at startup.

A valid signature tells the driver, and the user, that the board came from Jankyneering and was tested before shipping. That is the entire purpose. It exists so support requests can be routed correctly, not to control who builds the hardware.

### What signing does not do

The driver will never refuse to run on an unsigned board. An unsigned EEPROM produces a log line at warning level and nothing else:

```
HAT authenticity: unsigned EEPROM (no RSIG atom)
```

The board then works normally. The same applies to a signature that matches no known key. There is no kill switch, no reduced functionality, and no plan to add one. The design is CC BY-SA 4.0 and the driver is GPLv3, and blocking unsigned hardware would be at odds with both.

### Verifying a signature

With an I2CDriver adapter, reading boards as you insert them:

```bash
eeprom-sign batch-readback \
    --public hat_public.pem \
    --eeprom 24c256 \
    --port /dev/tty.usbserial-XXXXXXXX \
    --auto-detect
```

Or from a binary image:

```bash
eeprom-sign verify eeprom_signed.bin --public hat_public.pem
```

Install the tool with `pip install eeprom-sign`, or on macOS:

```bash
brew tap fred-corp/tap
brew install eeprom-sign
```

---

## Support for boards you built yourself

Software problems, driver build failures, and installation issues are fair game for a GitHub issue regardless of where your board came from.

Hardware problems on a board you had manufactured yourself are between you and your PCBA house. Hardware support is provided only for boards sold and tested through the store. See the [FAQ](faq.md) for the full breakdown.

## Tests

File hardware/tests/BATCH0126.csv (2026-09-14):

Batch Number | Serial number | TX Power (dBm) | RX Sensitivity (dBm)
0126 | 001 | 2.7 | -118
0126 | 002 | 2.6 | -118
0126 | 003 | 2.6 | -118
0126 | 004 | 2.6 | -118
0126 | 005 | 2.8 | -118
0126 | 006 | 2.6 | -119
0126 | 007 | 2.5 | -118
0126 | 008 | 2.9 | -118
0126 | 009 | 2.6 | -118
0126 | 010 | 2.6 | -118
0126 | 011 | 2.7 | -118
0126 | 012 | 2.7 | -118
0126 | 013 | 2.6 | -118
0126 | 014 | 2.5 | -118
0126 | 015 | 2.5 | -118
0126 | 016 | 2.4 | -118
0126 | 017 | 2.4 | -118
0126 | 018 | 2.5 | -118
0126 | 019 | 2.5 | -118
0126 | 020 | 2.1 | -118
0126 | 021 | 2.2 | -118
0126 | 022 | 2.5 | -118
0126 | 023 | 2.5 | -118
0126 | 024 | 2.4 | -118
0126 | 025 | 2.6 | -118
0126 | 026 | 2.7 | -118
0126 | 027 | 2.6 | -118
0126 | 028 | 2.6 | -118
0126 | 029 | 2.7 | -118
0126 | 030 | 2.6 | -118
0126 | 031 | 2.4 | -118
0126 | 032 | 2.5 | -118
0126 | 033 | 2.5 | -118
0126 | 034 | 2.7 | -118
0126 | 035 | 2.5 | -118
0126 | 036 | 2.5 | -118
0126 | 037 | 2.3 | -118
0126 | 038 | 2.4 | -118
0126 | 039 | 2.5 | -118
0126 | 040 | 2.5 | -118
0126 | 041 | 2.4 | -118
0126 | 042 | 2.5 | -118
0126 | 043 | 2.4 | -118
0126 | 044 | 2.5 | -118
0126 | 045 | 2.4 | -118
0126 | 046 | 2.5 | -118
0126 | 047 | 2.4 | -118
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

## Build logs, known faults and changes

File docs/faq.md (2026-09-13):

# FAQ

## Contents

- [What is this?](#what-is-this)
- [How do I install this quickly?](#how-do-i-install-this-quickly)
- [I don't trust your script. How can I build this manually?](#i-dont-trust-your-script-how-can-i-build-this-manually)
- [Which modes does it support?](#which-modes-does-it-support)
- [Why do you sign the EEPROM if this is open source?](#why-do-you-sign-the-eeprom-if-this-is-open-source-are-you-blocking-us-from-reusing-the-design)
- [How do I ask for support?](#how-do-i-ask-for-support)
- [Help, my driver says the board isn't genuine!](#help-my-driver-says-the-board-isnt-genuine)
- [Can I use an external reference clock?](#can-i-use-an-external-reference-clock)
- [What is the OLED header for?](#what-is-the-oled-header-for)
- [Is there a case?](#is-there-a-case)
- [Which Raspberry Pi should I use?](#which-raspberry-pi-should-i-use)
- [Do I need a licence to transmit?](#do-i-need-a-licence-to-transmit)
- [Can I put a power amplifier on it?](#can-i-put-a-power-amplifier-on-it-and-run-a-proper-base-station)
- [Can I use this with GQRX, SDR++, or GNU Radio?](#can-i-use-this-with-gqrx-sdr-or-gnu-radio)
- [Where are the production files?](#where-are-the-production-files)
- [Is there a power amplifier board?](#is-there-a-power-amplifier-board)

---

## What is this?

µCell is an open-source SDR base station platform. The µCell BB board is a Raspberry Pi HAT built around an SX1255 transceiver. Paired with a Pi and one of the supported software stacks, it runs a base station in whichever mode that software implements.

The hardware designs, the case models, the drivers, and the EEPROM tooling are all in this repository. The board is OSHWA certified under [BE000024](https://certification.oshwa.org/be000024.html).

## How do I install this quickly?

Fit the board to the Pi, flash Raspberry Pi OS Lite (64-bit), boot, and run:

```bash
bash -c "$(curl -fsSL https://raw.githubusercontent.com/Jankyneering/mu-cell/main/install-mu-cell-sw.sh)"
```

Reboot when prompted, then run it again. That gets the driver and overlay in place. Radio software is installed separately from its own project. The [quick start guide](quickStartGuide.md) has links and configuration notes for each one.

## I don't trust your script. How can I build this manually?

Reasonable. [buildDriver.md](buildDriver.md) walks through every step the script performs for the driver and overlay. The script itself is in the repository root if you want to read it first.

## Which modes does it support?

TETRA is where the project started, through Bluestation and Flowstation, and it is the best tested path today. It is not a limit. The board is a plain SoapySDR device, so MMDVM-IQ brings DMR, D-Star, YSF, P25, and analog FM to the same hardware, and general SDR software can use it for anything else.

The intention is to support as many voice modes as we can get working. If you bring up a mode we have not documented, tell us about it.

## Why do you sign the EEPROM if this is open source? Are you blocking us from reusing the design?

No. The driver will never refuse to run on an unsigned board, and there is no plan to change that.

Signing exists to answer one question: did this specific board come from Jankyneering and get tested before shipping? That matters for support. A few concrete cases:

- Someone reports 8 dB less transmit power than the spec sheet. If the board is signed, it passed a radio test set before shipping, and the problem is probably configuration or a damaged antenna. If it is unsigned, a substituted inductor in the matching network is a likelier explanation, and the debugging goes in a completely different direction.
- Someone's board is not detected at all. A signed EEPROM proves the EEPROM was written correctly at the factory, which rules out a whole category of causes immediately.
- A clone appears with a looser reference clock. Signing keeps reports about those separate from reports about boards we can actually vouch for.

None of this restricts you. The hardware is CC BY-SA 4.0 and certified by OSHWA, and the software is GPLv3. You can build the design, modify it, and sell it.

## How do I ask for support?

It depends on what is broken.

| Problem | Where to go |
|---|---|
| Driver, overlay, install script | Open a [GitHub issue](https://github.com/Jankyneering/mu-cell/issues) |
| Radio software behaviour or configuration | That project's issue tracker |
| Hardware fault on a board bought from the store | Contact [store.fredcorp.cc](http://store.fredcorp.cc/) |
| Hardware fault on a board from another seller | Contact that seller |
| Hardware fault on a board you had manufactured | Contact your PCBA house |

<!-- TODO: add the actual support contact route for store purchases, whether that is an email, a form, or a shop account. -->

The split is not about gatekeeping. Driver problems are reproducible and benefit from being public, so issues are the right venue for everyone. Hardware faults need someone who has the board's test record, which only the seller has.

## Help, my driver says the board isn't genuine!

Not a problem, and the board will work anyway. The message is a warning, not an error.

If you built the board yourself or bought it from a third party, this is expected. Your EEPROM either has no signature or is signed with a key the driver does not know about. Nothing else changes.

If you bought it from the store and it previously reported as genuine, or it reports `SIGNATURE_MISMATCH`, your driver is probably older than your board. New production batches are signed with new keys, and those keys ship with driver updates. Re-run the install script to update:

```bash
bash -c "$(curl -fsSL https://raw.githubusercontent.com/Jankyneering/mu-cell/main/install-mu-cell-sw.sh)"
```

See [updating](quickStartGuide.md#updating) for what that does.

If the message is `NO_KEYS_COMPILED_IN`, the driver was built with an empty `public_keys/` directory. Signature checking is simply off in that build.

## Can I use an external reference clock?

Yes. There is a third U.FL connector for it. The board ships using the onboard 0.5 ppm TCXO, and switching to the external input means cutting JP1 on the back and bridging the jumper across. See [hardware.md](hardware.md#external-clock).

## What is the OLED header for?

A standard 0.96 inch SSD1306 display, on the Pi's I2C bus. The forthcoming µCell Display module uses the same panel alongside a rotary encoder and status LEDs. There is no µCell software support for it yet, but nothing stops you using an existing SSD1306 library in the meantime. Pinout is in [hardware.md](hardware.md#oled-display-header).

## Is there a case?

Yes. 3D printable case designs are in the `hardware` directory, under the same CC BY-SA 4.0 licence as the boards. They print without supports on a standard FDM machine. See [hardware.md](hardware.md#cases).

If you print one and something needs adjusting, open a pull request with the change and a note on your print settings.

## Which Raspberry Pi should I use?

The Pi 3, 4, 5, and Zero 2W are all supported by the driver. Some radio software ships separate builds for the Pi 5 and for earlier models, so check which asset you need when you install it. A Zero 2W works but compiles slowly if you build from source.

## Do I need a licence to transmit?

Yes, in essentially every jurisdiction. The frequencies this board is used on are licensed, and transmitting without authorisation is illegal in most countries. This is your responsibility, not the project's. If you want to experiment without a licence, look into what your national regulator permits, whether that is an amateur allocation you hold a licence for, a test licence, or a shielded enclosure.

## Can I put a power amplifier on it and run a proper base station?

You can, but the filtering is on you, and it is not optional.

The SX1255 is a mobile device part. Its selectivity is sized for a handset transmitting a fraction of a watt into its own antenna, not for a site with a kilowatt of RF nearby. On the bench, an interfering signal at -40 dBm and 10 MHz away from the receive frequency is already enough to degrade the rated sensitivity. An amplified transmitter is orders of magnitude stronger than that and much closer in frequency.

So if you amplify, budget for proper transmit rejection on the receive path, a duplexer or cavity filtering as appropriate, and transmit filtering in the amplifier chain. Bolt a 100 W amplifier straight onto the board and you will have a transmitter that works and a receiver that goes deaf every time you key it.

See [hardware.md](hardware.md#adding-an-amplifier).

## Can I use this with GQRX, SDR++, or GNU Radio?

Yes. The board registers as a standard SoapySDR device. Use the device string `driver=mucell`. See the [quick start guide](quickStartGuide.md#other-soapysdr-software).

## Where are the production files?

Under `/hardware/mu-cell-bb/v1.3/production`, alongside the schematics and PCB layouts. [muCellBBManufacture.md](muCellBBManufacture.md) covers what is in the package, the stackup we order, and which component substitutions will quietly ruin your RF performance.

## Is there a power amplifier board?

Not yet. The µCell PA Mini, at roughly 1 W, is designed but still needs work before it is ready to manufacture. The µCell Display module is closer to done. See [hardware.md](hardware.md) for the current roadmap, and the question above before you reach for an amplifier of your own.

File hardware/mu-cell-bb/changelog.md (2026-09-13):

# µCell BB Changelog

## v1.3 - Batch feedback upgrades

> 2026/07

- Routing updates
  - Moved some vias that were in the middle of component pads to avoid soldering issues during production.
- Net updates
  - Changes 3.3V on accessory header to use the 3.3V rail from the Raspberry Pi instead of the µCell BB's 3.3V rail, to avoid overloading or adding noise to the µCell BB's 3.3V regulator when using high-current accessories.
- Silkscreen updates
  - Bumped version number to v1.3
  - Bumped date to 2026/07

## v1.2 - Small updates

> 2026/05

- Footprint updates
  - Changed Y1 footprint to the smaller 2016 package, as they tend to be more precise anyway (the larger 2520 package could fit both sizes, but reflow issues were observed during a mid-scale production run).
- Component updates
  - Set the RF Can to be excluded from BOM by default
- Silkscreen updates
  - Bumped version number to v1.2

## v1.1 - Minor refinements

> 2026/04

- Footprint updates
  - Reworked RF Can GND pad vias
    - Via placement is now more regular, signal routing to the SX1255 is more direct.
  - Removed SMA connector pads
    - The TX and RX connectors would have been too close together, causing potential interference and signal integrity issues. By removing the SMA connector pads, we can ensure better performance and reliability of the RF signals.
  - Put pin 6 of EEPROM programming headers to GND
    - This allows an external programmer to detect when a programming header is connected, to then automatically trigger the programming process.
- Silkscreen updates
  - Added OSHW logo to top side
  - Bumped version number to v1.1
  - Removed pad numbers next to clock selection jumpers
  - Added "Serial n°" Field to bottom side

## v1.0 - Initial release

> 2026/04

- Performance on par with [SXCeiver](https://sxceiver.com)

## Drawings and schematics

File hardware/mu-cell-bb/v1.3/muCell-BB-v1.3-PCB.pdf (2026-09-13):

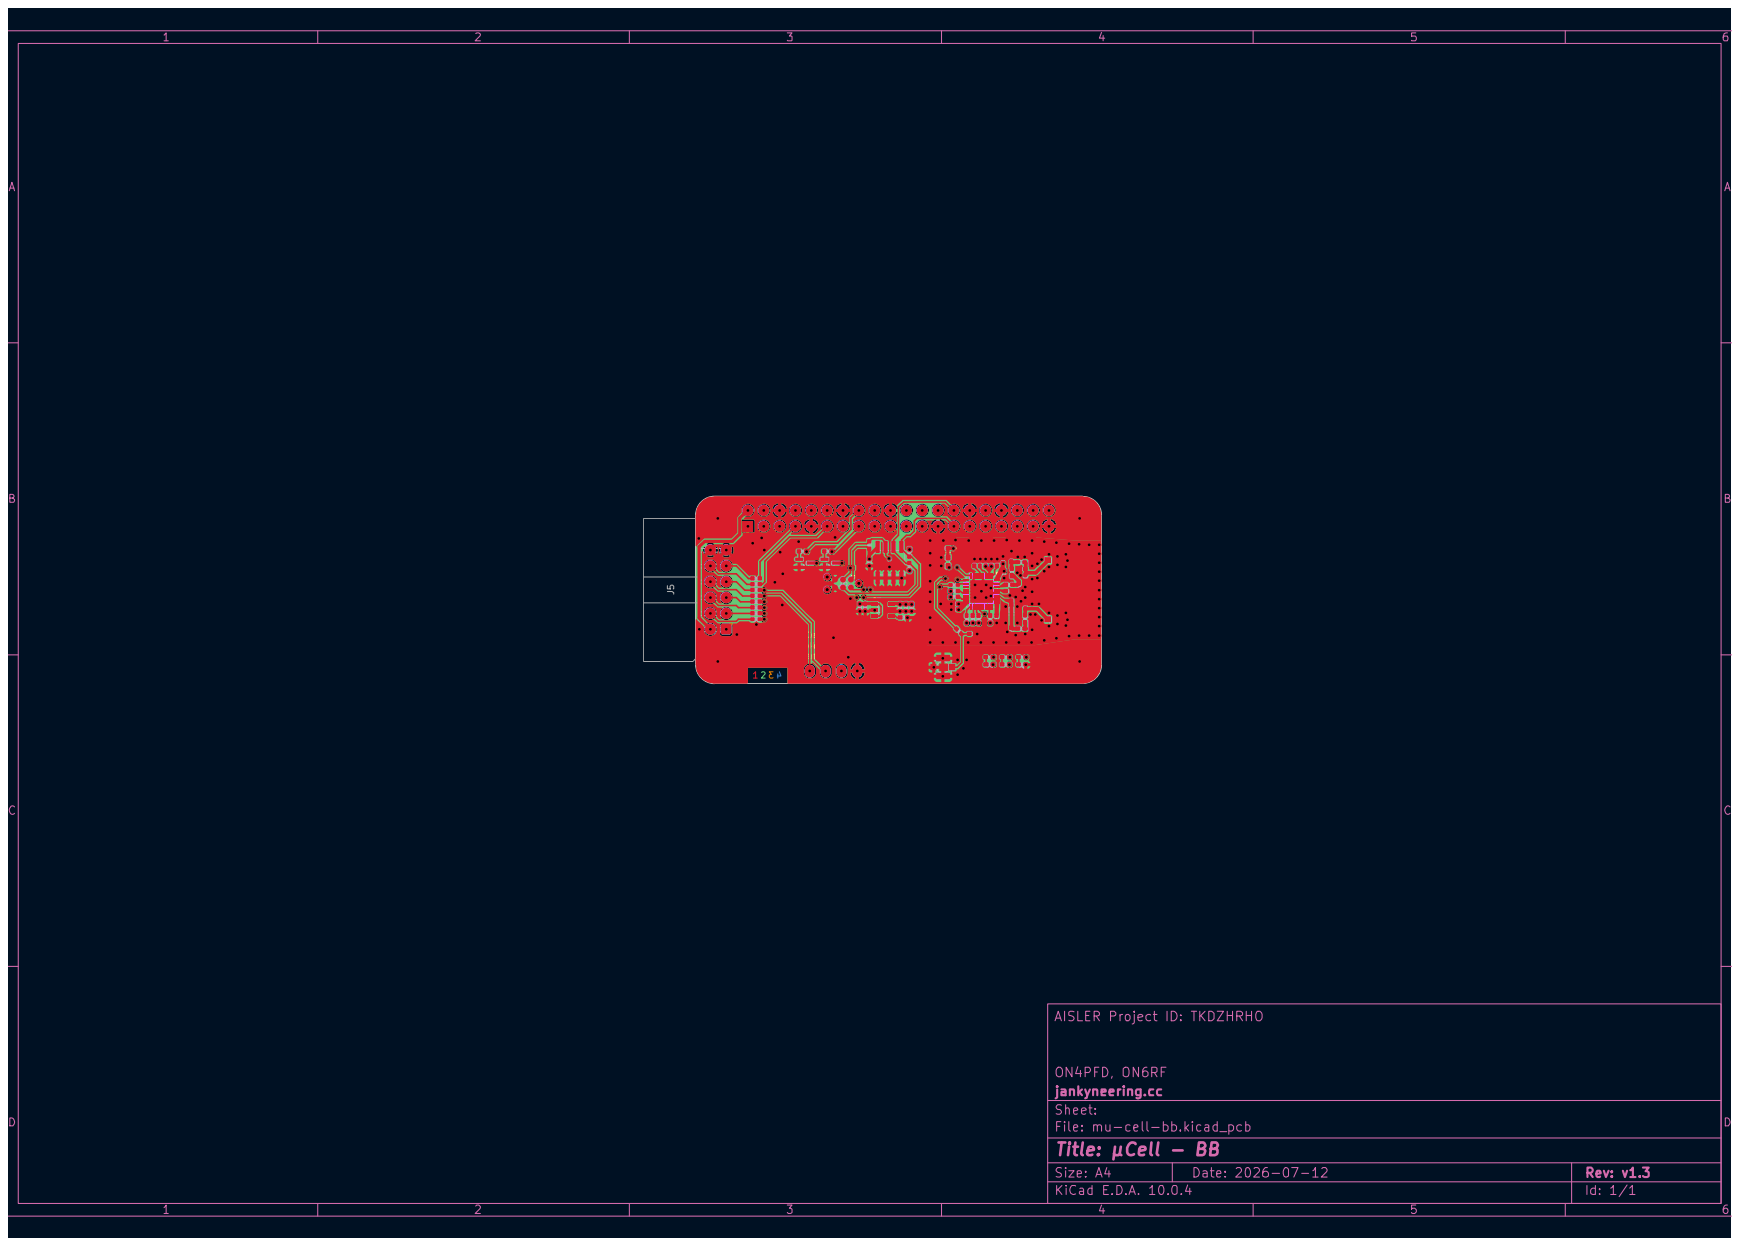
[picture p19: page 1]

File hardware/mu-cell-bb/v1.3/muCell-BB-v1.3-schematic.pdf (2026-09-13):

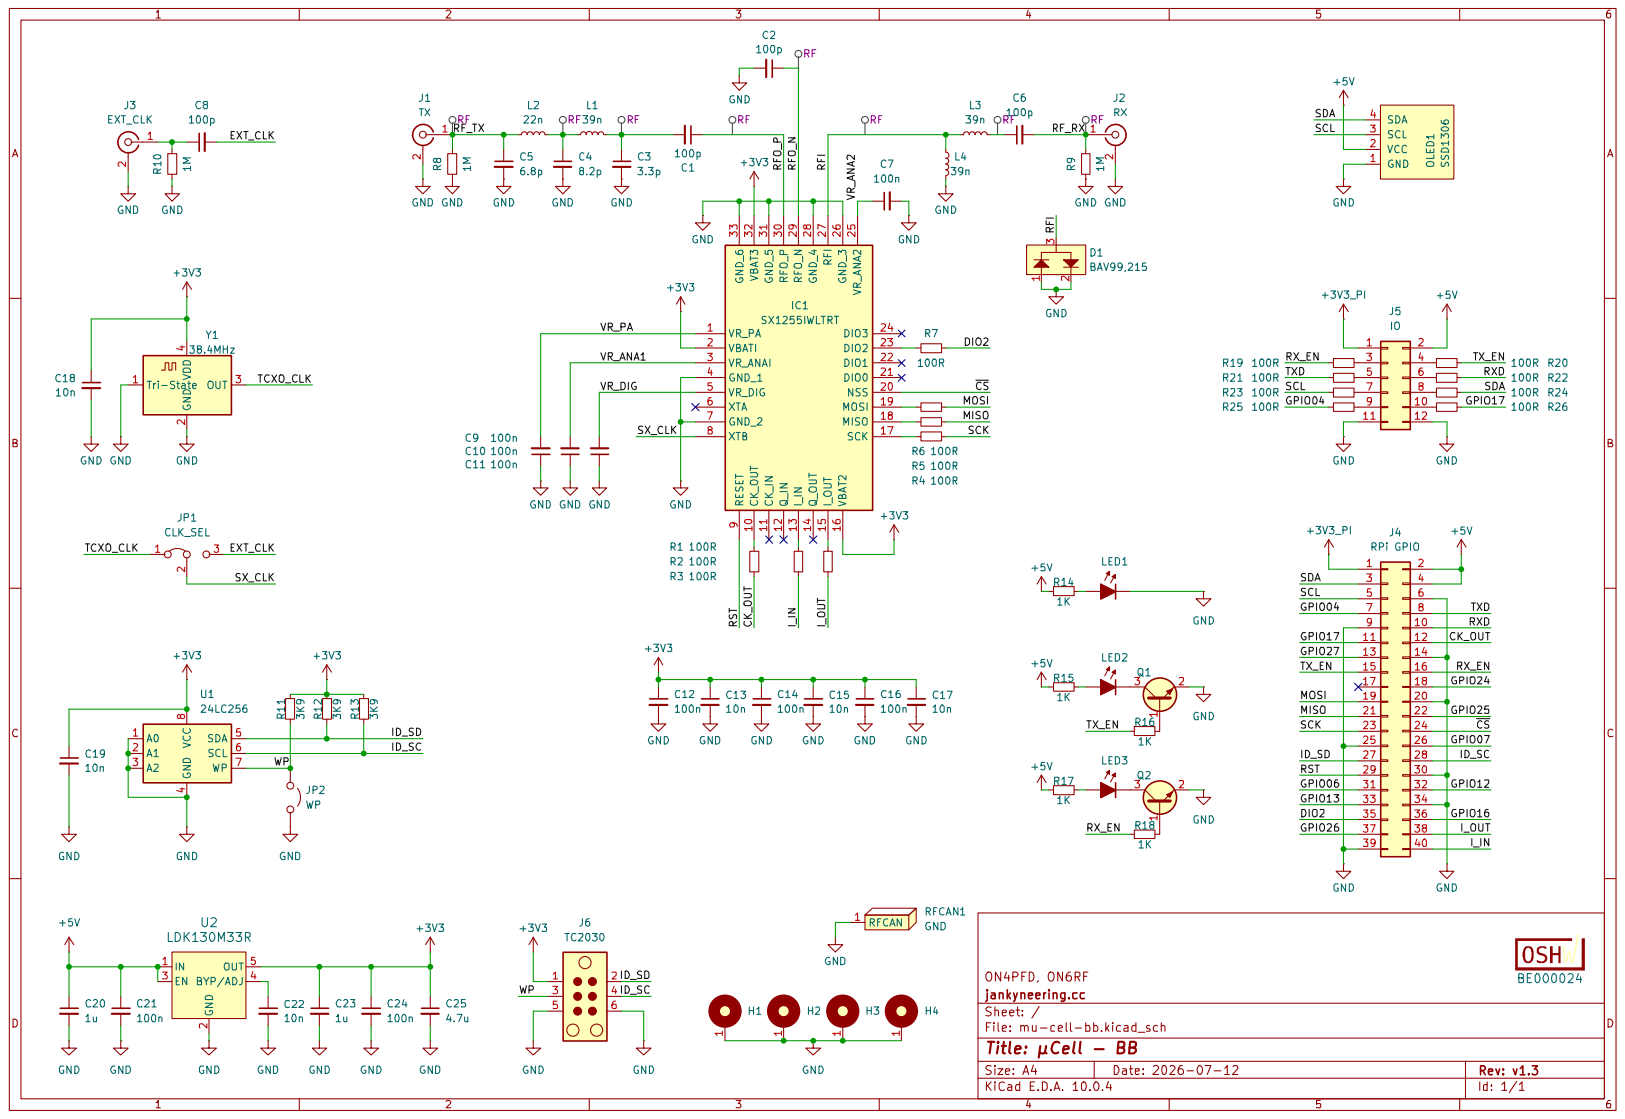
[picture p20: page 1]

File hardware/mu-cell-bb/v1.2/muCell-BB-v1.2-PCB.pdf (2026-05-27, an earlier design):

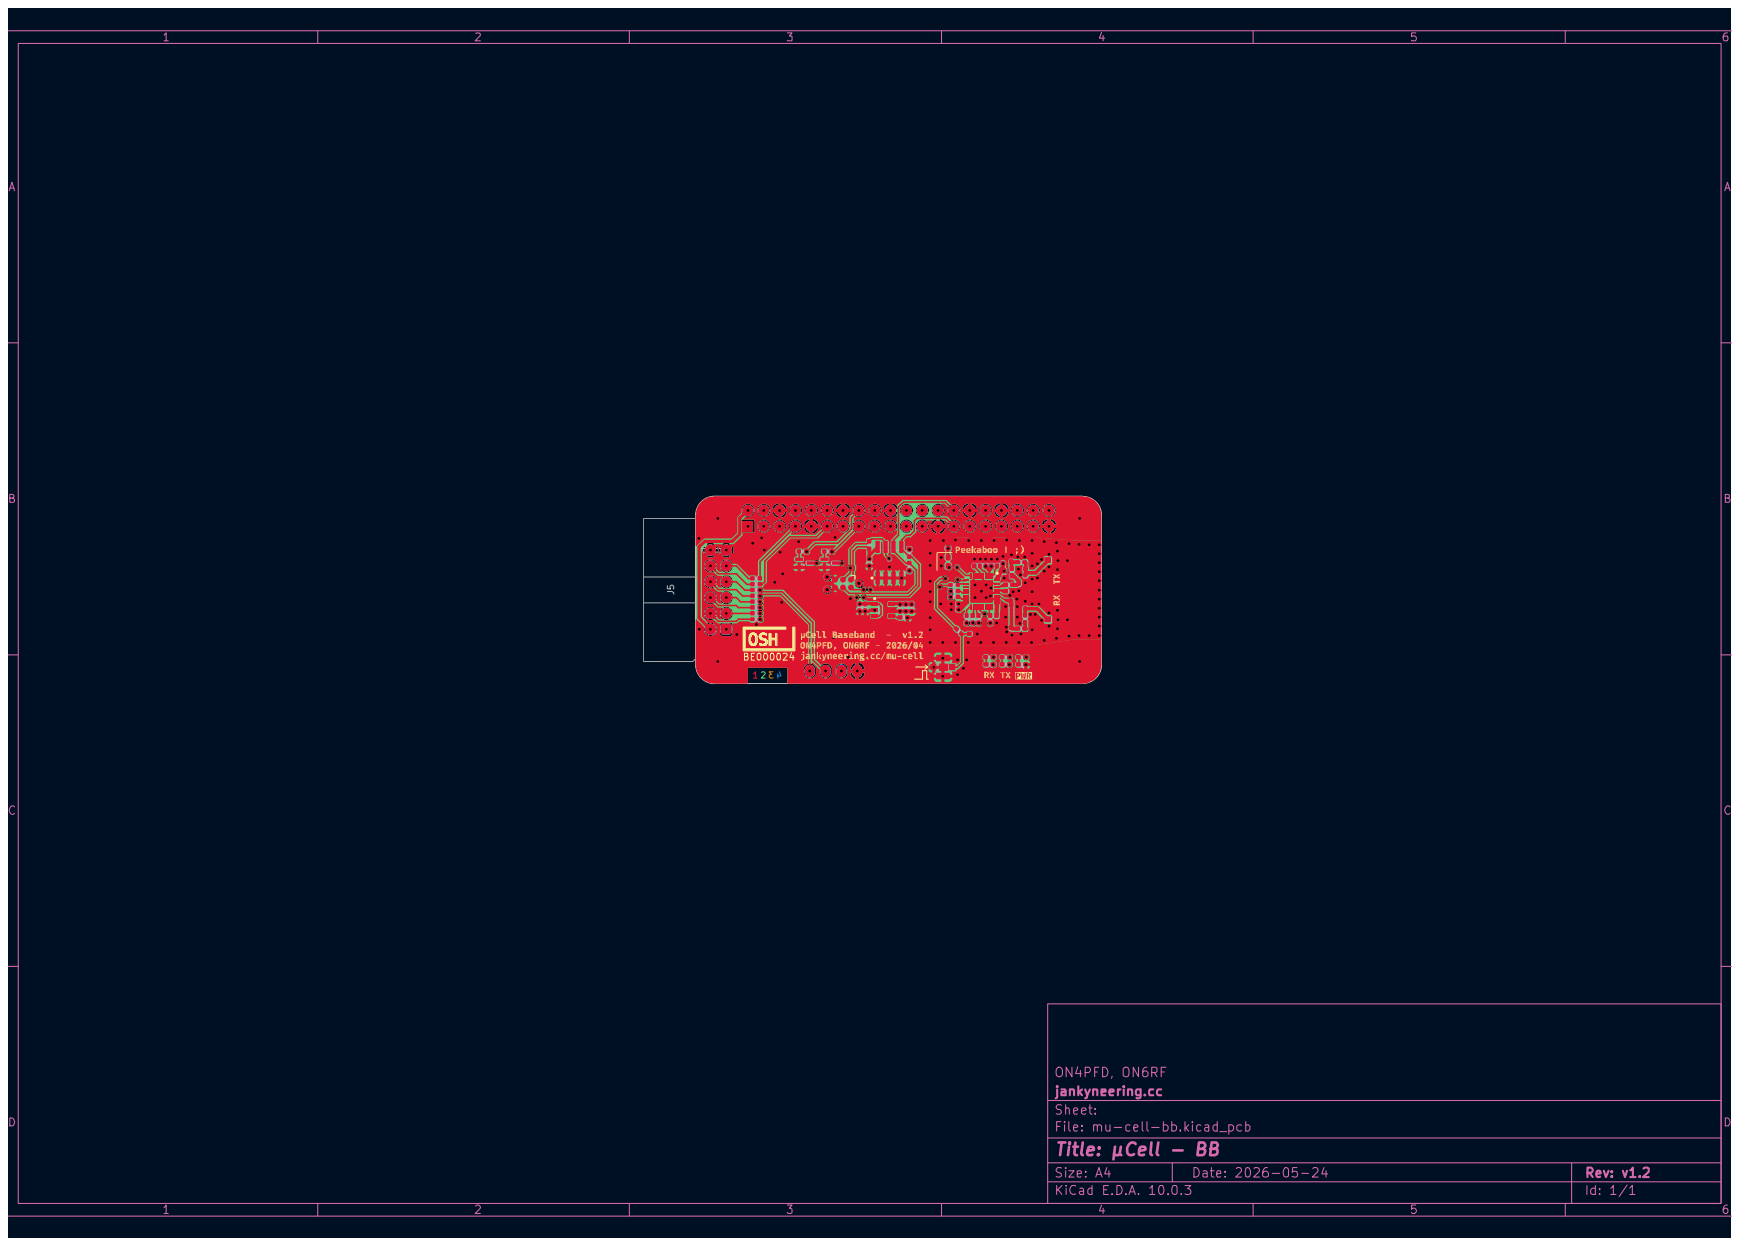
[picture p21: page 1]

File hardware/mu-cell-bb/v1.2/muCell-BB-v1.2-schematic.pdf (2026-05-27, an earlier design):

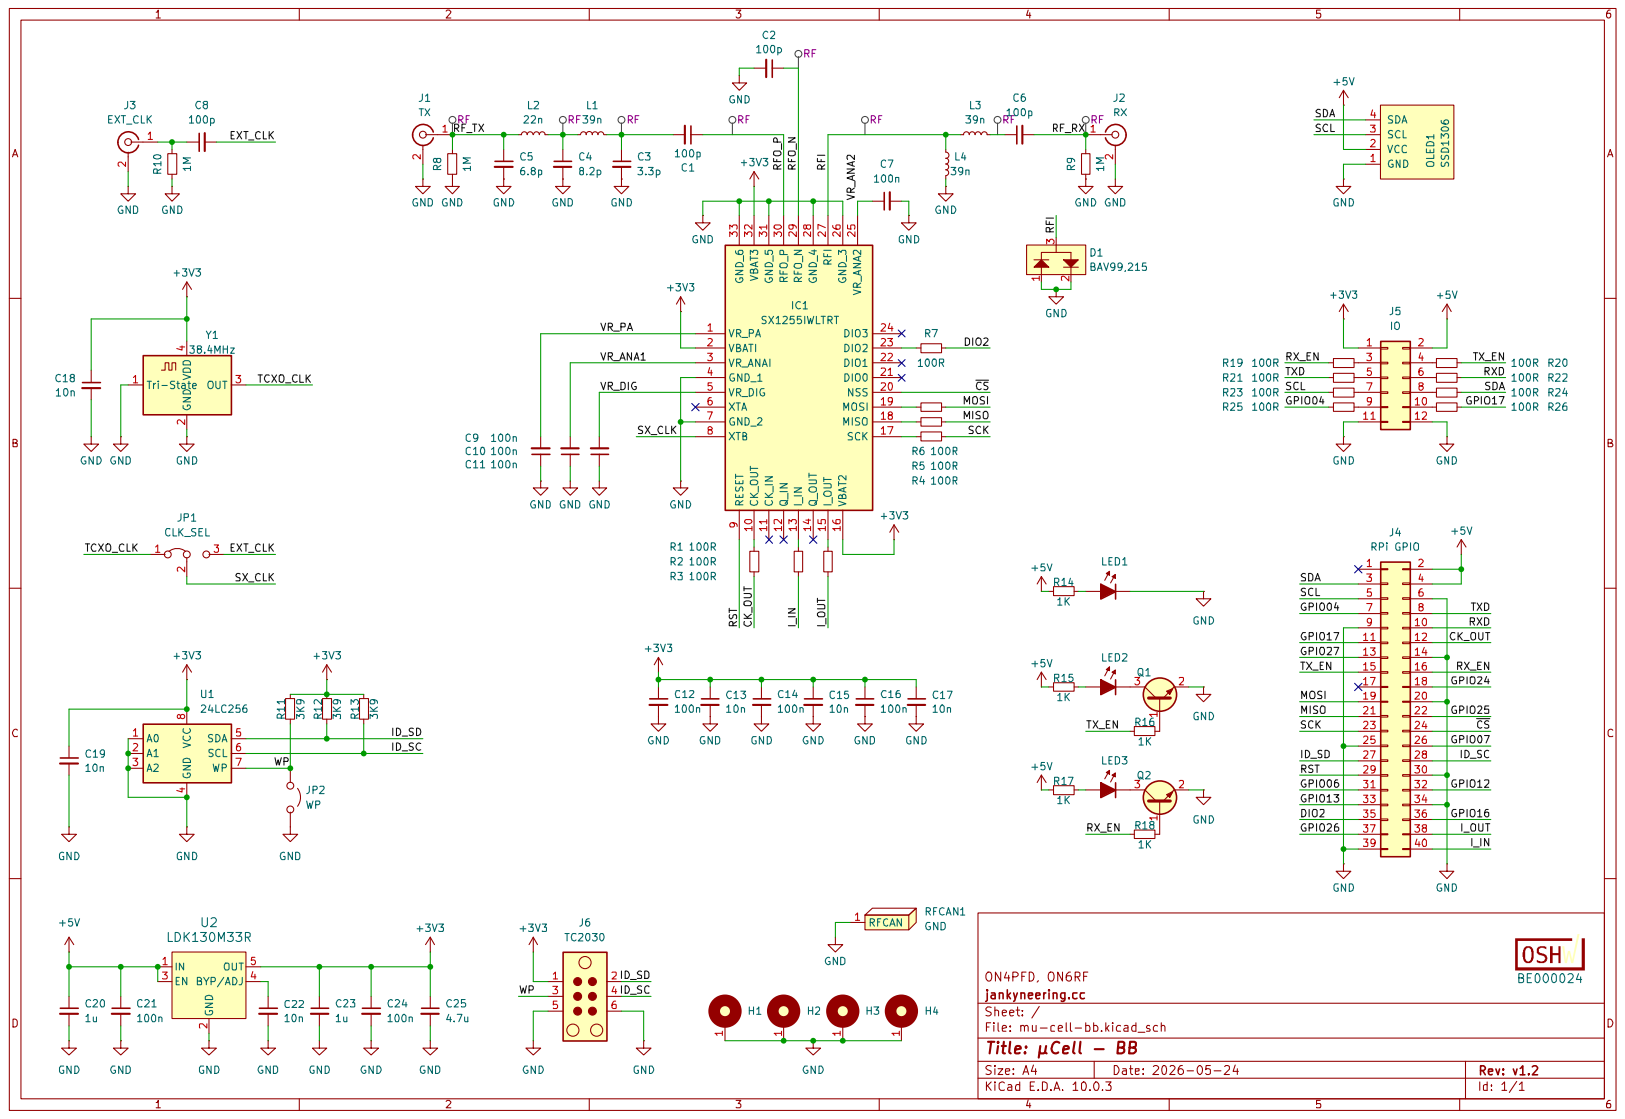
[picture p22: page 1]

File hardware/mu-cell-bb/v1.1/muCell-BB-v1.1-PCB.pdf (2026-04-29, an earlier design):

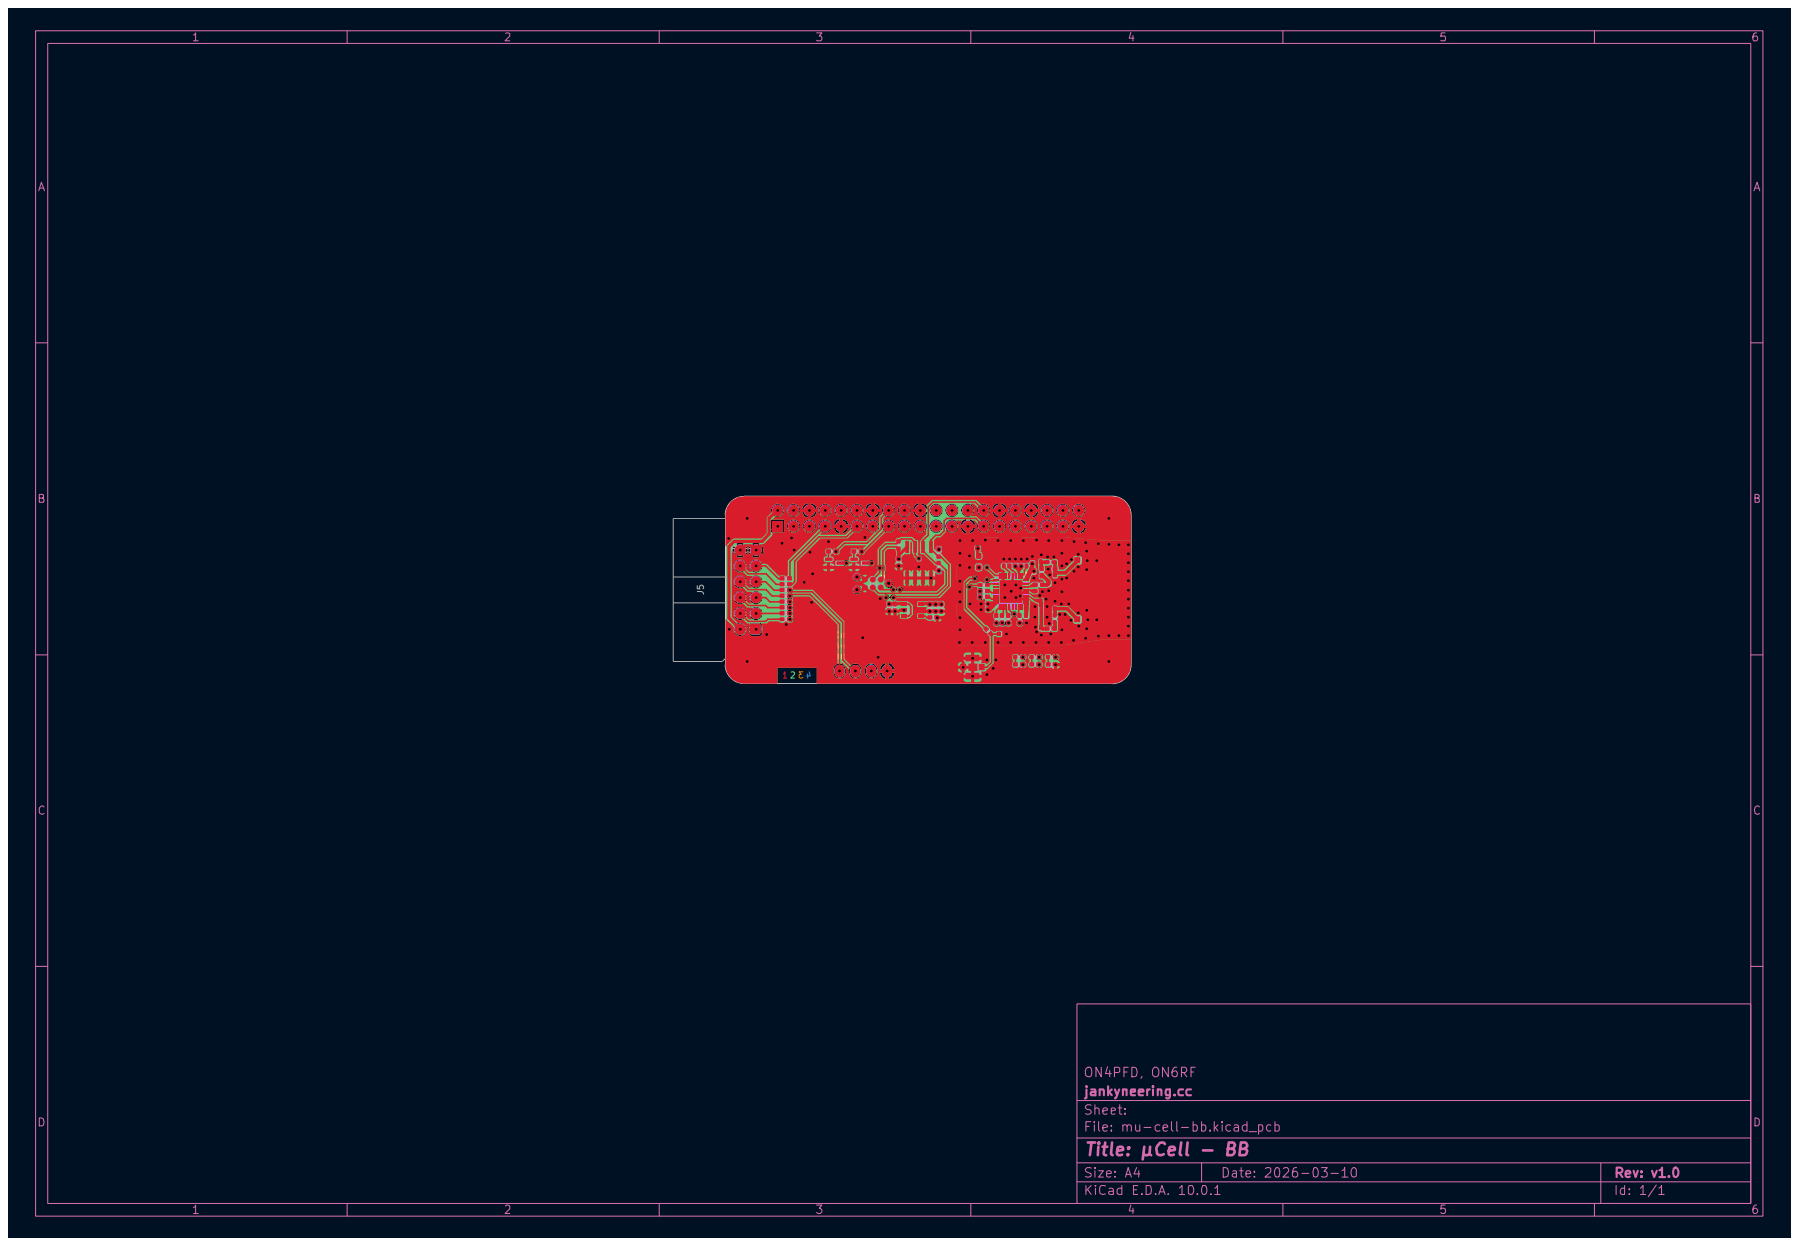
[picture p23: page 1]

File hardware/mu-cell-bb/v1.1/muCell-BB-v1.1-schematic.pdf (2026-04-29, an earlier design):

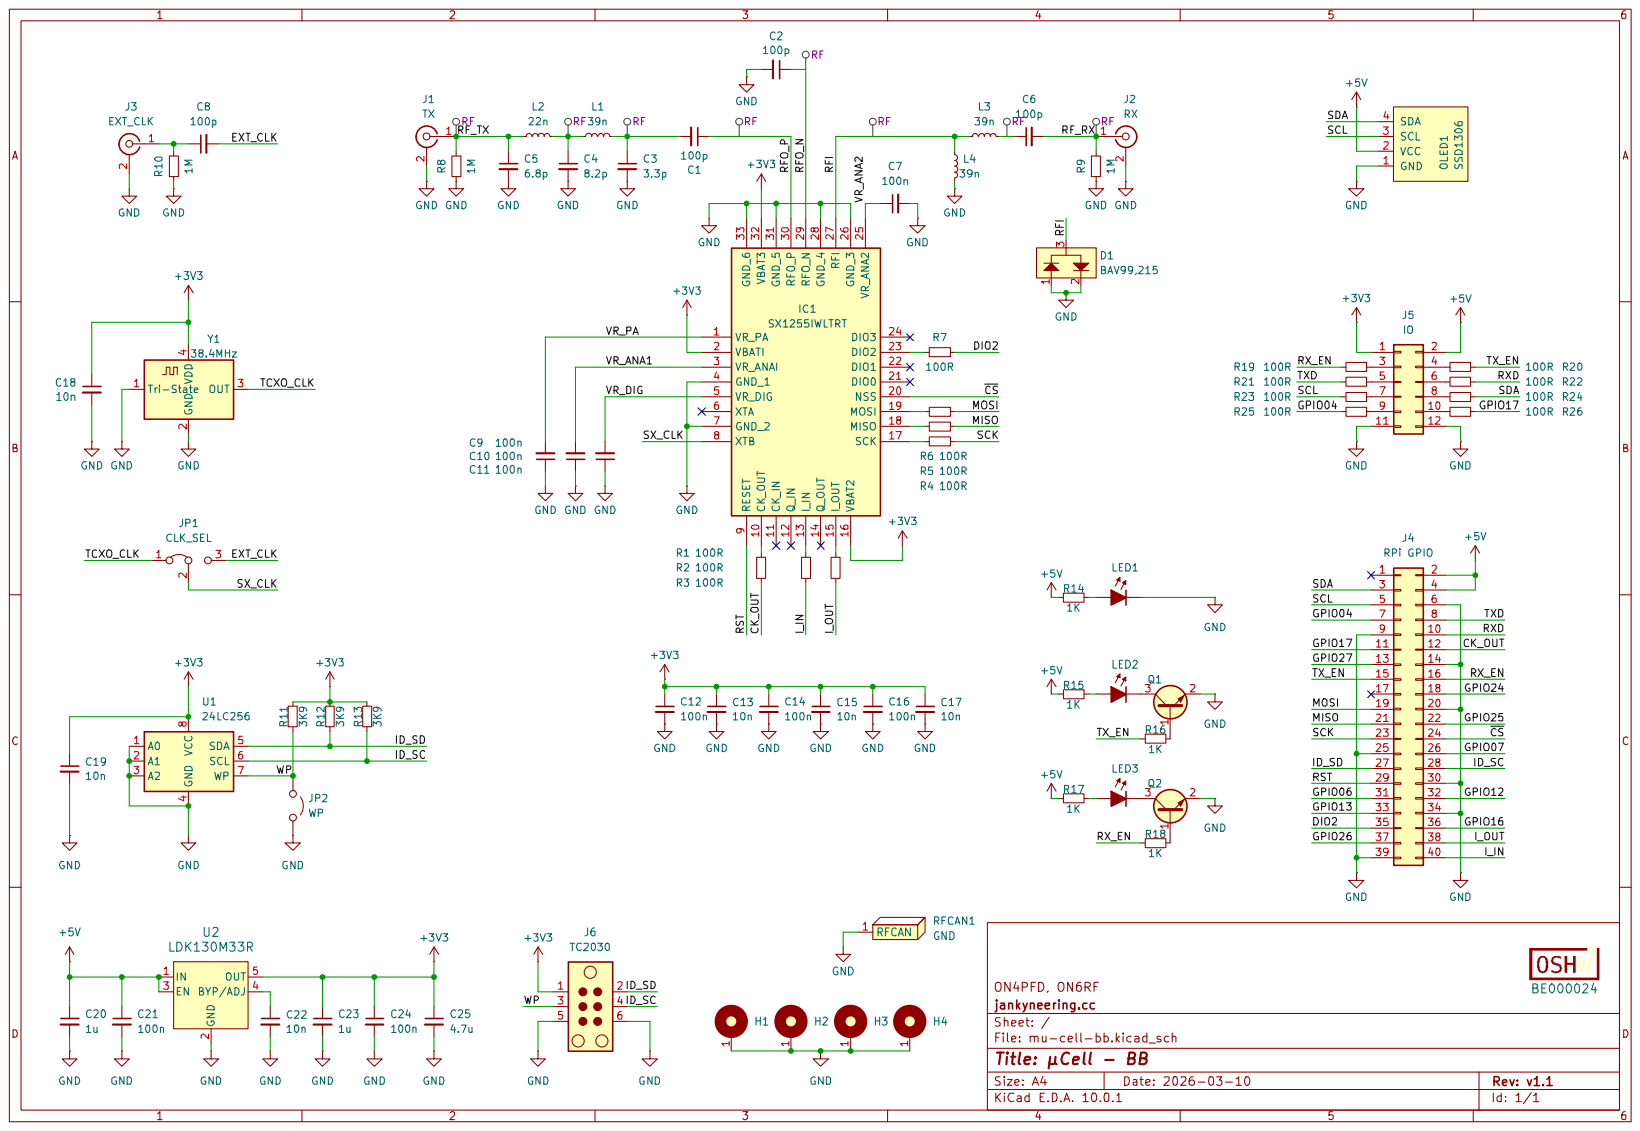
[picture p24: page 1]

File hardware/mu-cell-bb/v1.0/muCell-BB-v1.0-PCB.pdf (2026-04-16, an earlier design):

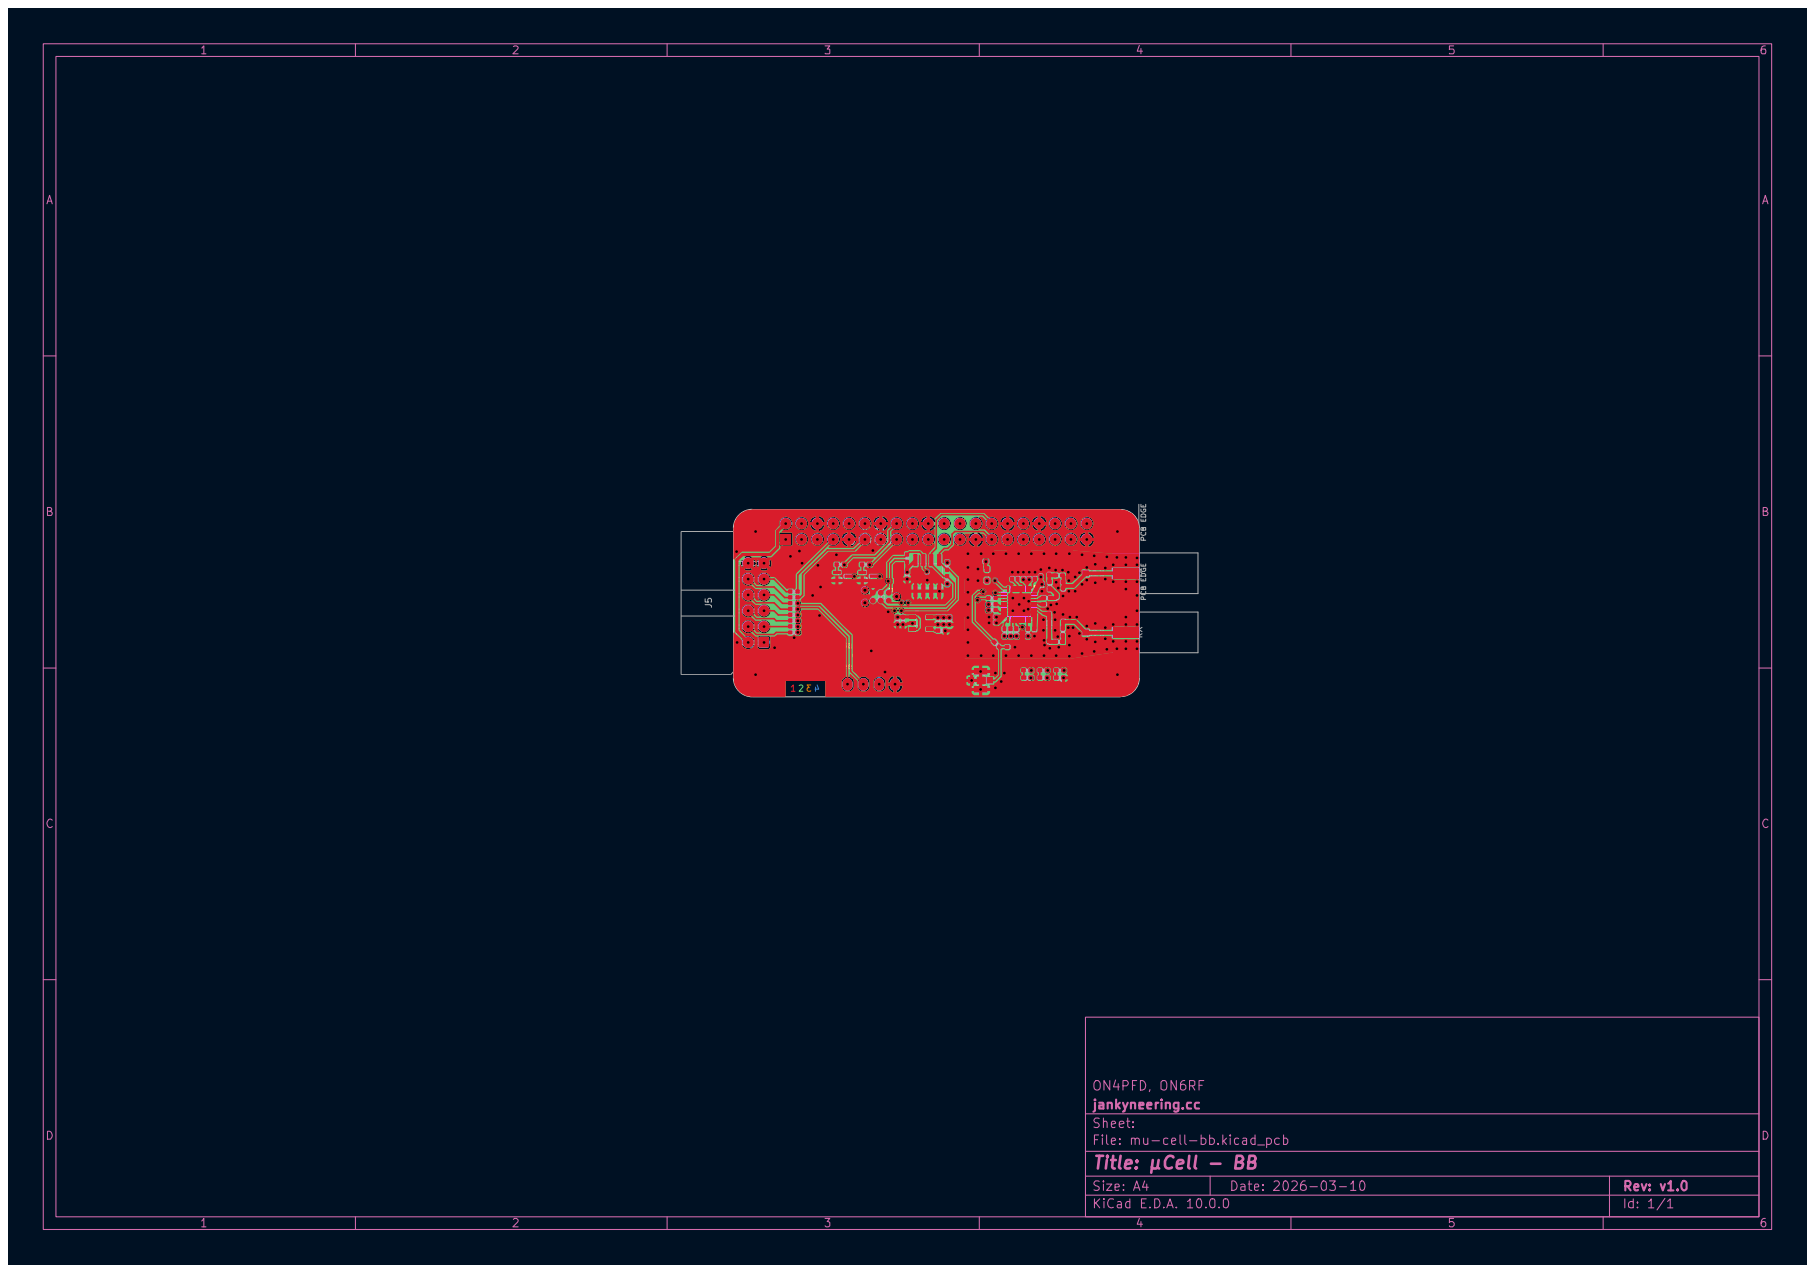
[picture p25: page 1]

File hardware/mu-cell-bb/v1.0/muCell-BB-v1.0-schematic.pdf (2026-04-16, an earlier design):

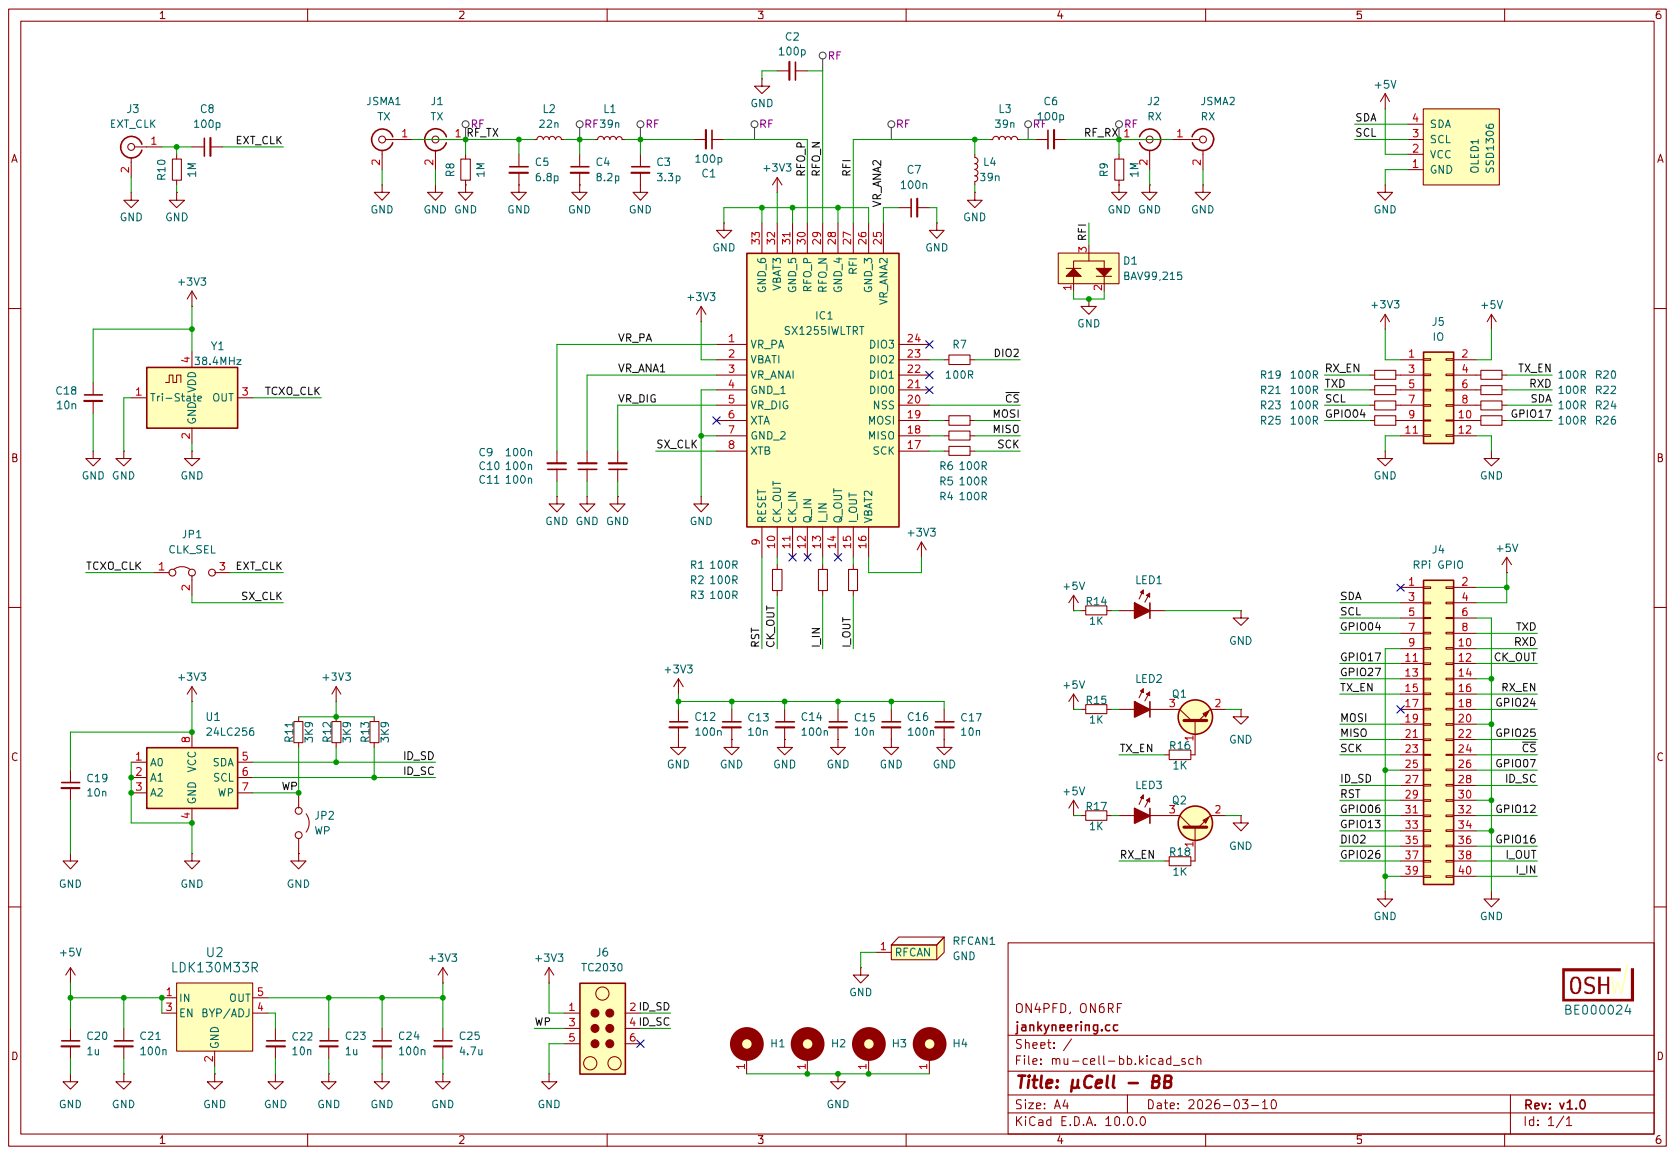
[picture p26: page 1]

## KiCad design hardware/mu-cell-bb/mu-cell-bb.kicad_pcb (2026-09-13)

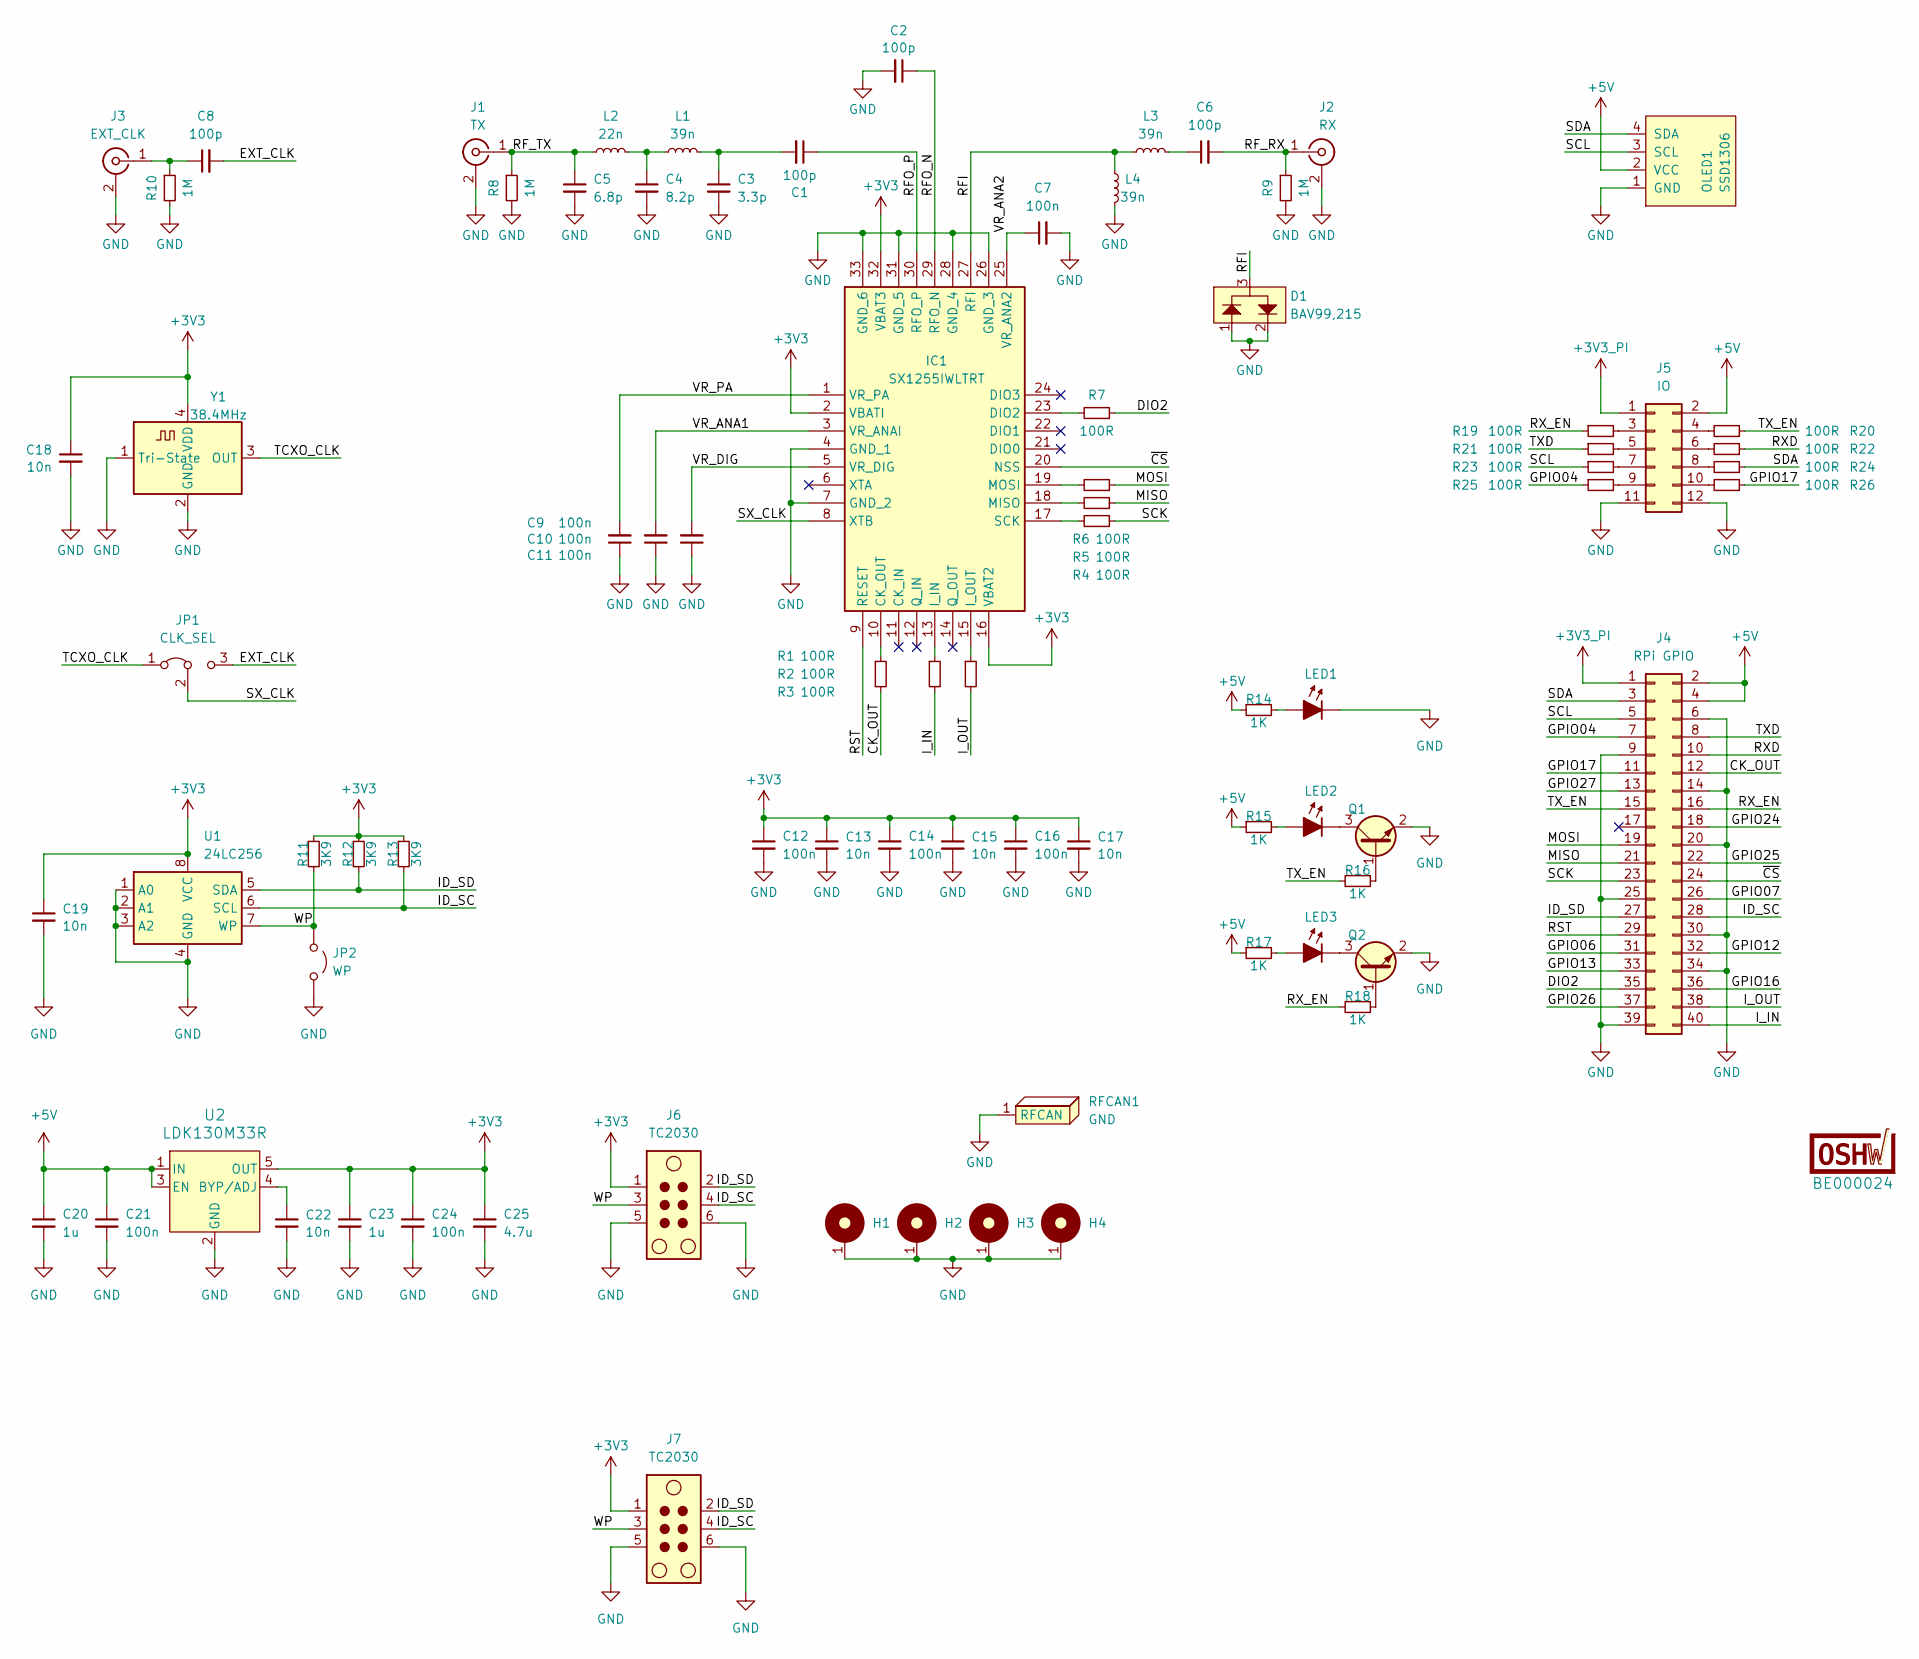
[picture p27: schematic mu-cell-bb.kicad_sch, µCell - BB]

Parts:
BE000024: OSHW-Certification-Mark-Stacked_8x7mm_SilkMask
C1, C2, C6, C8: 100p; C_0402_1005Metric_Pad0.74x0.62mm_HandSolder; MPN GCM1555C1H101FA16D; LCSC Part C2941926
C3: 3.3p; C_0402_1005Metric_Pad0.74x0.62mm_HandSolder; MPN GCM1555C1H3R3GA16D; LCSC Part C2941931
C4: 8.2p; C_0402_1005Metric_Pad0.74x0.62mm_HandSolder; MPN 0402CG8R2G500NT; LCSC Part C2857971
C5: 6.8p; C_0402_1005Metric_Pad0.74x0.62mm_HandSolder; MPN GCM1555C1H6R8FA16D; LCSC Part C1864373
C7, C9, C10, C11, C12, C14, C16, C21, C24: 100n; C_0402_1005Metric_Pad0.74x0.62mm_HandSolder; MPN CC0402KRX7R7BB104; LCSC Part C60474
C13, C15, C17, C18, C19, C22: 10n; C_0402_1005Metric_Pad0.74x0.62mm_HandSolder; MPN CC0402KRX7R9BB103; LCSC Part C60133
C20, C23: 1u; C_0402_1005Metric_Pad0.74x0.62mm_HandSolder; MPN CL05A105KO5NNNC; LCSC Part C29266
C25: 4.7u; C_0402_1005Metric_Pad0.74x0.62mm_HandSolder; MPN CL05A475MP5NRNC; LCSC Part C23733
D1: BAV99,215; SOT-23-3; MPN BAV99,215; LCSC Part C2500
H1, H2, H3, H4: MountingHole_M3_3.2mm_Pad; MountingHole_3.2mm_Pad
IC1: SX1255IWLTRT; QFN50P500X500X80-33N-D; Mouser Part Number 947-SX1255IWLTRT
J1: TX; U.FL_Vertical_Passthrough; MPN BWU.FL-IPEX1; LCSC Part C5137195
J2: RX; U.FL_Vertical_Passthrough; MPN BWU.FL-IPEX1; LCSC Part C5137195
J3: EXT_CLK; U.FL_Vertical_GND; MPN BWU.FL-IPEX1; LCSC Part C5137195
J4: RPi GPIO; PinSocket_2x20_P2.54mm_Vertical
J5: IO; IDC-Header_2x06_P2.54mm_Horizontal
J6, J7: TC2030; Tag-Connect_TC2030-IDC-NL_2x03_P1.27mm_Vertical
JP1: CLK_SEL; SolderJumper-3_P1.3mm_Bridged12_RoundedPad1.0x1.5mm_NumberL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
JP2: WP; SolderJumper-2_P1.3mm_Open_RoundedPad1.0x1.5mm
L1, L3, L4: 39n; L_0402_1005Metric_Pad0.77x0.64mm_HandSolder; MPN 0402CS-39NXGRW; LCSC Part C40399699
L2: 22n; L_0402_1005Metric_Pad0.77x0.64mm_HandSolder; MPN 0402CS-22NXGRW; LCSC Part C22440906
LED1: Red; LED_0402_1005Metric_Pad0.77x0.64mm; MPN F.0402.00003/P2-0402R1TS2-045T-001; LCSC Part C7496803
LED2: Amber; LED_0402_1005Metric_Pad0.77x0.64mm; MPN BL-HJC37A-AV-TRB; LCSC Part C5123495
LED3: Green; LED_0402_1005Metric_Pad0.77x0.64mm; MPN 16-213/GHC-YR1S1/3T; LCSC Part C74338
OLED1: SSD1306; OLED_128x64_I2C
Q1, Q2: BC817-40W; SOT-323_SC-70; MPN LBC817-40WT1G; LCSC Part C383187
R1, R2, R3, R4, R5, R6, R7, R19, R20, R21, R22, R23, R24, R25, R26: 100R; R_0402_1005Metric_Pad0.72x0.64mm_HandSolder; MPN RC0402FR-07100RL; LCSC Part C106232
R8, R9, R10: 1M; R_0402_1005Metric_Pad0.72x0.64mm_HandSolder; MPN 0402WGF1004TCE; LCSC Part C26083
R11, R12, R13: 3K9; R_0402_1005Metric_Pad0.72x0.64mm_HandSolder; MPN FRC0402F3901TS; LCSC Part C2909346
R14, R15, R16, R17, R18: 1K; R_0402_1005Metric_Pad0.72x0.64mm_HandSolder; MPN RC0402FR-071KL; LCSC Part C106235
RFCAN1: GND; 2118707-4 CAN; MPN 2118707-4; LCSC Part C22418535
U1: 24LC256; SOIC-8_3.9x4.9mm_P1.27mm; MPN 24LC256-E/SN; LCSC Part C615210
U2: LDK130M33R; SOT23-5L_1P75X3P05X0P95_STM; MPN LDK130M33R; LCSC Part C2969807
Y1: 38.4MHz; Crystal_SMD_2016-4Pin_2.0x1.6mm; MPN TG2016SMN 38.4000M-MCGNNM3; LCSC Part C1987359

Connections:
+3V3: C12.1, C13.1, C14.1, C15.1, C16.1, C17.1, C18.1, C19.1, C23.1, C24.1, C25.1, IC1.2 (VBATI), IC1.16 (VBAT2), IC1.32 (VBAT3), J6.1, J7.1, R11.1, R12.1, R13.1, U1.8 (VCC), U2.5 (OUT), Y1.4 (VDD)
+3V3_PI: J4.1, J5.1
+5V: C20.1, C21.1, J4.2, J4.4, J5.2, OLED1.2 (VCC), R14.1, R15.1, R17.1, U2.1 (IN), U2.3 (EN)
/CK_OUT: J4.12, R1.2
/DIO2: J4.35, R7.1
/EXT_CLK: C8.2, JP1.3 (B)
/GPIO04: J4.7, R25.1
/GPIO06: J4.31
/GPIO07: J4.26
/GPIO12: J4.32
/GPIO13: J4.33
/GPIO16: J4.36
/GPIO17: J4.11, R26.1
/GPIO24: J4.18
/GPIO25: J4.22
/GPIO26: J4.37
/GPIO27: J4.13
/ID_SC: J4.28, J6.4, J7.4, R13.2, U1.6 (SCL)
/ID_SD: J4.27, J6.2, J7.2, R12.2, U1.5 (SDA)
/I_IN: J4.40, R2.2
/I_OUT: J4.38, R3.2
/MISO: J4.21, R5.1
/MOSI: J4.19, R6.1
/RFI: D1.3, IC1.27 (RFI), L3.2, L4.2
/RFO_N: C2.1, IC1.29 (RFO_N)
/RFO_P: C1.1, IC1.30 (RFO_P)
/RF_RX: C6.2, J2.1 (In), R9.1
/RF_TX: C5.1, J1.1 (In), L2.2, R8.1
/RST: IC1.9 (RESET), J4.29
/RXD: J4.10, R22.1
/RX_EN: J4.16, R18.2, R19.1
/SCK: J4.23, R4.1
/SCL: J4.5, OLED1.3 (SCL), R23.1
/SDA: J4.3, OLED1.4 (SDA), R24.1
/SX_CLK: IC1.8 (XTB), JP1.2 (C)
/TCXO_CLK: JP1.1 (A), Y1.3 (OUT)
/TXD: J4.8, R21.1
/TX_EN: J4.15, R16.2, R20.1
/VR_ANA1: C10.2, IC1.3 (VR_ANAI)
/VR_ANA2: C7.1, IC1.25 (VR_ANA2)
/VR_DIG: C11.2, IC1.5 (VR_DIG)
/VR_PA: C9.2, IC1.1 (VR_PA)
/WP: J6.3, J7.3, JP2.1 (A), R11.2, U1.7 (WP)
/~CS: IC1.20 (NSS), J4.24
GND: C2.2, C3.2, C4.2, C5.2, C7.2, C9.1, C10.1, C11.1, C12.2, C13.2, C14.2, C15.2, C16.2, C17.2, C18.2, C19.2, C20.2, C21.2, C22.2, C23.2, C24.2, C25.2, D1.1, D1.2, H1.1, H2.1, H3.1, H4.1, IC1.4 (GND_1), IC1.7 (GND_2), IC1.26 (GND_3), IC1.28 (GND_4), IC1.31 (GND_5), IC1.33 (GND_6), J1.2 (Ext), J2.2 (Ext), J3.2 (Ext), J4.6, J4.9, J4.14, J4.20, J4.25, J4.30, J4.34, J4.39, J5.11, J5.12, J6.5, J6.6, J7.5, J7.6, JP2.2 (B), L4.1, LED1.1 (K), OLED1.1 (GND), Q1.2 (E), Q2.2 (E), R8.2, R9.2, R10.2, RFCAN1.1 (RFCAN_1), U1.1 (A0), U1.2 (A1), U1.3 (A2), U1.4 (GND), U2.2 (GND), Y1.1 (Tri-State), Y1.2 (GND)
unnamed: C1.2, C3.1, L1.1
unnamed: C4.1, L1.2, L2.1
unnamed: C6.1, L3.1
unnamed: IC1.10 (CK_OUT), R1.1
unnamed: IC1.23 (DIO2), R7.2
unnamed: IC1.13 (I_IN), R2.1
unnamed: IC1.15 (I_OUT), R3.1
unnamed: IC1.18 (MISO), R5.2
unnamed: IC1.19 (MOSI), R6.2
unnamed: IC1.17 (SCK), R4.2
unnamed: C8.1, J3.1 (In), R10.1
unnamed: J5.3, R19.2
unnamed: J5.4, R20.2
unnamed: J5.5, R21.2
unnamed: J5.6, R22.2
unnamed: J5.7, R23.2
unnamed: J5.8, R24.2
unnamed: J5.9, R25.2
unnamed: J5.10, R26.2
unnamed: LED1.2 (A), R14.2
unnamed: LED2.2 (A), R15.2
unnamed: LED2.1 (K), Q1.3 (C)
unnamed: LED3.2 (A), R17.2
unnamed: LED3.1 (K), Q2.3 (C)
unnamed: Q1.1 (B), R16.1
unnamed: Q2.1 (B), R18.1
unnamed: C22.1, U2.4 (BYP/ADJ)

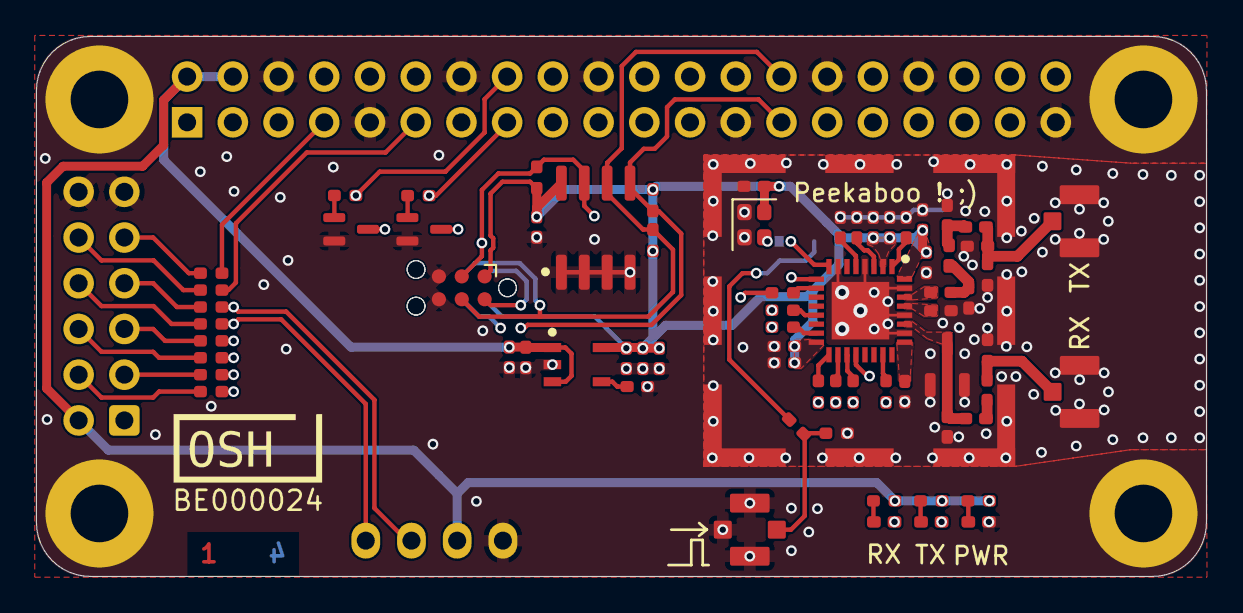
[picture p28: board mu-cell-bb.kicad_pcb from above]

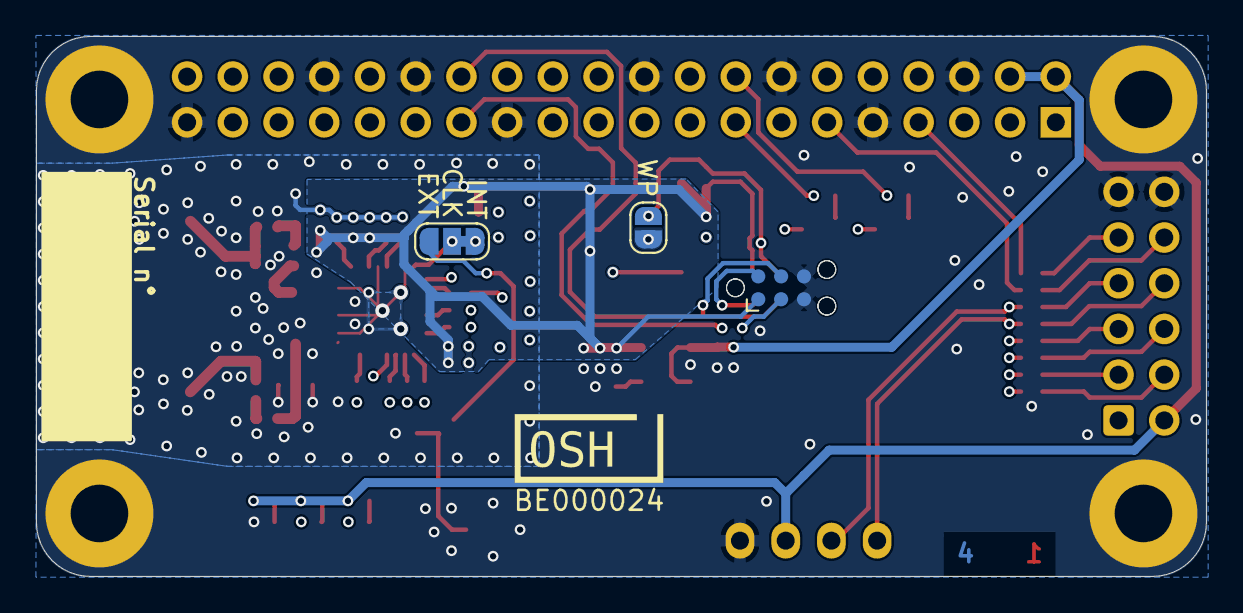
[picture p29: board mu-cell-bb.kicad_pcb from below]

Board: 4 copper layers, 65.0 x 30.0 mm, 82 parts (5 on the bottom side), 63 nets.

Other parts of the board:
BE000024#2: OSHW-Certification-Mark-Stacked_8x7mm_SilkMask

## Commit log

2026-03-03 Added schematics for mu-Cell BB
    [SOT23-5L_1P75X3P05X0P95_STM.step, mu-cell-bb.kicad_pcb, mu-cell-bb.kicad_sch]
2026-03-03 added gitignore for KiCAD files
2026-03-03 updated schematic
    [mu-cell-bb.kicad_sch]
2026-03-03 started work on PCB
    [mu-cell-bb.kicad_pcb, mu-cell-bb.kicad_sch]
2026-03-03 added symbols, worked on PCB
    [OLED_128x64_I2C.step, mu-cell-bb.kicad_pcb, mu-cell-bb.kicad_sch]
2026-03-03 added parts
    [SMA_Side.step, U.FL_Vertical.step, mu-cell-bb.kicad_pcb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]
2026-03-03 Added footprint for SX
    [SX1255IWLTRT.stp]
2026-03-03 added PCB changes and parts
    [2118707-4-CAN.STEP, mu-cell-bb.kicad_pcb, mu-cell-bb.kicad_sch]
2026-03-03 moved files
    [2118707-4-CAN.STEP, OLED_128x64_I2C.step, Oscillator_SMD_SeikoEpson_SG210-4Pin_2.5x2.0mm.step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]
2026-03-03 updated footprints
    [mu-cell-bb.kicad_sch]
2026-03-04 Routed majority of components
    [mu-cell-bb.kicad_pcb, mu-cell-bb.kicad_sch]
2026-03-04 added LCSC parts, finished routing
    [mu-cell-bb.kicad_pcb, mu-cell-bb.kicad_sch]
2026-03-04 linted readme, moved stuff on PCB
    [mu-cell-bb.kicad_pcb, mu-cell-bb.kicad_sch]
2026-03-04 added sim files
    [Stub.qucs.sch, TL_Sim.qucs.sch, amp_qucs_test.qucs.sch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]
2026-03-04 saved changes on PCB
    [mu-cell-bb.kicad_pcb, mu-cell-bb.kicad_sch]
2026-03-04 added TX and RX front end simulations
    [RX_Front-end.qucs.sch, TX_Front-end.qucs.sch]
2026-03-05 late night PCB changes
    [mu-cell-bb.kicad_pcb]
2026-03-05 updated silkscreens on PCB
    [mu-cell-bb.kicad_pcb, mu-cell-bb.kicad_sch]
2026-03-07 updated RX an TX front end
    [RX_Front-end.qucs.sch, TX_Front-end.qucs.sch, mu-cell-bb.kicad_sch]
2026-03-08 updated sim data
    [RX_Front-end.qucs.sch, TX_Front-end.qucs.sch]
2026-03-08 updated TX and RX front ends
    [mu-cell-bb.kicad_pcb, mu-cell-bb.kicad_sch]
2026-03-08 updated PCB
    [mu-cell-bb.kicad_pcb]
2026-03-10 added eeprom programming header, updated part numbers
    [mu-cell-bb.kicad_pcb, mu-cell-bb.kicad_sch]
2026-03-10 made final changes before ordering first batch
    [RX_Front-end.qucs.sch, mu-cell-bb.kicad_pcb, mu-cell-bb.kicad_sch]
2026-03-10 added fabrication output for manufacturing
    [bom.csv, designators.csv, positions.csv]
2026-03-30 migrated to KiCAD 10.0
    [mu-cell-bb.kicad_pcb, mu-cell-bb.kicad_sch]
2026-04-16 added muCell-BB v1.0 folder
    [bom.csv, designators.csv, positions.csv]
2026-04-27 added base files for SoapyMuCell driver Directly inspired from SoapySX, adding signature checks for µCell BB Hats
2026-04-28 updatet errors in driver sources
2026-04-29 added muCell-BB v1.1 files
    [bom.csv, designators.csv, mu-cell-bb.kicad_pcb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]
2026-04-29 enhanced EEPROM parsing logic and add driver alias registration for SoapyMuCell
2026-04-29 refactor EEPROM parsing logic to reconstruct signed payload from device-tree data
2026-04-29 refactor, AGN, removed `sx` driver label that caused issues with stability
2026-05-14 added µCell drivers submodule
2026-05-22 updated driver commit tag
2026-05-27 added v1.2 PCB files
    [mu-cell-bb.kicad_pcb, mu-cell-bb.kicad_sch, muCell_-_BB_v1.2_bom.csv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]
2026-05-27 added rudimentary pogo-pin fixture
    [mu-cell-bb_testbench-fixture.FCStd]
2026-06-11 updated drivers
2026-07-12 added v1.3 files
    [mu-cell-bb.kicad_pcb, mu-cell-bb.kicad_sch, muCell_-_BB_v1.3_bom.csv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]
2026-09-13 Added cases for 3D printing (WIP)
    [Case-Case_Top_Pi4.3mf, Case.FCStd, Case_Bottom_Pi4.3mf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]
2026-09-13 Fixed schematic paths
2026-09-14 added upload script for Inventree test results
    [BATCH0126.csv]
